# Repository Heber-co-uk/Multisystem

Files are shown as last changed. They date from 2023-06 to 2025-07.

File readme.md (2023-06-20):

# Multisystem all-in-one console motherboard designed by Heber Ltd. for MiSTer and the DE10-nano FPGA platform

### [Multisystem I/O console motherboard](https://github.com/Heber-co-uk/Multisystem/tree/main/Multisystem_All_in_One_PCB)
This all in one motherboard (console) is designed by Heber Ltd. and is released as open-source hardware for the MiSTer FPGA community and project. This console style motherboard provides SCART, VGA, Analog and Digital audio outputs, 128MB of SDRAM, SNAC with automatic level-shifters. Multisystem also has a built in 7 port USB 2.0 Hub. HDMI Isolation, fan connections, power switch, Ethernet, 2nd SD CARD interface and a dedicated expansion connector for various cartridges.

### [Multisystem 3D printed enclosure](https://www.printables.com/model/505755-mister-multisystem-v6x-2023-classic-gaming-console)
An open source enclosure is also available – designed for 3D printing (CC-BY-SA-4.0) commercial use license, over on Printables. Various other enclosures, modules, cartridges and expansion’s are also being made available all the time. Please check back for future updates and new 3D prints. 3D enclosure designed by Richard Horne @RichRap3D for Heber and the Multisystem / MiSTer project.

### Various images of the Multisystem PCB can be found [here](https://github.com/Heber-co-uk/Multisystem/tree/main/images)

### A comprehensive user manual for the Multisystem can be found [here](https://github.com/Heber-co-uk/Multisystem/tree/main/Manual)
Please check the manual if you have any questions about assembly and use of the Multisystem or the MiSTer FPGA project.

### [The official RTC daughter board is also supported on the Multisystem](https://github.com/MiSTer-devel/Hardware_MiSTer/tree/master/Addons/RTC)
This board provides real time clock. It's plugged into LTC connector.

### [Please support the MiSTer project and its creators & developers](https://patreon.com/FPGAMiSTer)
Please consider supporting the original creators for MiSTer and any of the FPGA Core developers over on Patreon or anywhere you can support or help them.

### [Alexey Melnikov](https://github.com/sorgelig)
The MiSTer project, electronics hardware, the Linux software and many FPGA cores would not have been possible without the dedicated efforts of the community, past projects like MiST and especially Alexey Melnikov for the porting over to the DE10-nano as MiSTer. Please support the project wherever you can.

### [MiSTer Forum](https://misterfpga.org/)
The MiSTer project forum can be found here.

### [RMC Retro - TheCave]( https://www.rmcretro.com/)
We would like to thank Neil at RMCRetro for the ongoing support of this project and many others for the Retro Gaming, classic computer and Arcade gaming communities. 

### [Heber Ltd.](https://heber.co.uk/) Heber are developing hardware for the Retro Gaming, classic computer and Arcade gaming communities. If you would like to know more, please visit our website or follow us on social media. 

## Notes
The PCB design and schematic is made in Altium, you will need to use Altium Designer v19.0 (or later) in order to view the source files. For convenience, [gerber files (*.zip)](https://github.com/Heber-co-uk/Multisystem/tree/main/Multisystem_All_in_One_PCB) are also included
and ready to submit to a PCB manufacturer of your choice.

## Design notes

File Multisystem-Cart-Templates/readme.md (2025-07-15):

# Heber Expansion Cartridge templates

KiCad templates for cartridges for the Multisystem and Multisystem2 / Future Multisystems.

Schematic includes the edge connector with appropriately labelled nets.

PCB includes the edge connector and a board outline.

The Multisystem cartridge also includes a micro USB 3.0 connector, which enables SNAC cartridges to be connected to other MiSTer FPGA systems. On the Multisystem, the V_SNAC signal from the edge connector and power from the USB connector will be at 5V or 3.3V depending on the voltage setting on the Multisystem, but on other MiSTer systems, the voltage from the USB connector is always 5V even when a level shifter is used. VBUS on the edge connector is current-limited 5V from the USB current limiting IC whereas 5V on the edge connector is from the main power input protected only by the main polyfuse. Also note that the SSRX and SSTX pairs are swapped in the micro USB connector; this is because the SSRX pins at the USB end connect to SSTX at the micro USB end of the cable and vice versa.

On Multisystem 2, V_SNAC is fixed at 3.3V and the level of the signals from the system are 3.3V. We recommend designing any SNAC cartridge for 5V devices with on-board level shifters so that they will be compatible with Multisystem and Multisystem 2. The common BSS138 level shifting circuit is sufficient and the pull-ups on the system side should be connected to V_SNAC for correct signal levels on the system side regardless of the position of the 5V/3.3V switch on Multisystem.

If you wish to make your own Cartridges for the Multisystem/Multisystem2, please use this template so they will be compatible.

## Board finish
Never use HASL. Use ENIG.

All official Heber cartridges feature hard gold plating on the edge contacts to improve the long term reliability of the contacts. This is an extra cost option available from most PCB manufacturers and is quite expensive to add if you are ordering prototypes; the boards will of course work without hard gold plating, but standard gold plating will wear off the pads quickly and reduce the reliability over the long term.

## Signals 
 - USB 2.0
 - GPIO Pins (3.3v)
 - Analogue input signals
 - +5V (2A max)
 - +3.3v (1A max)
 - GND
 - VBUS (Selectable voltage on the Multisystem board 3.3v or 5v)
 - Full SNAC/USER PORT
 - Digital Audio output
 - Analogue Audio output
 - RGBHV Analogue video output - various display modes & Standards.
 - Sync On Green signal

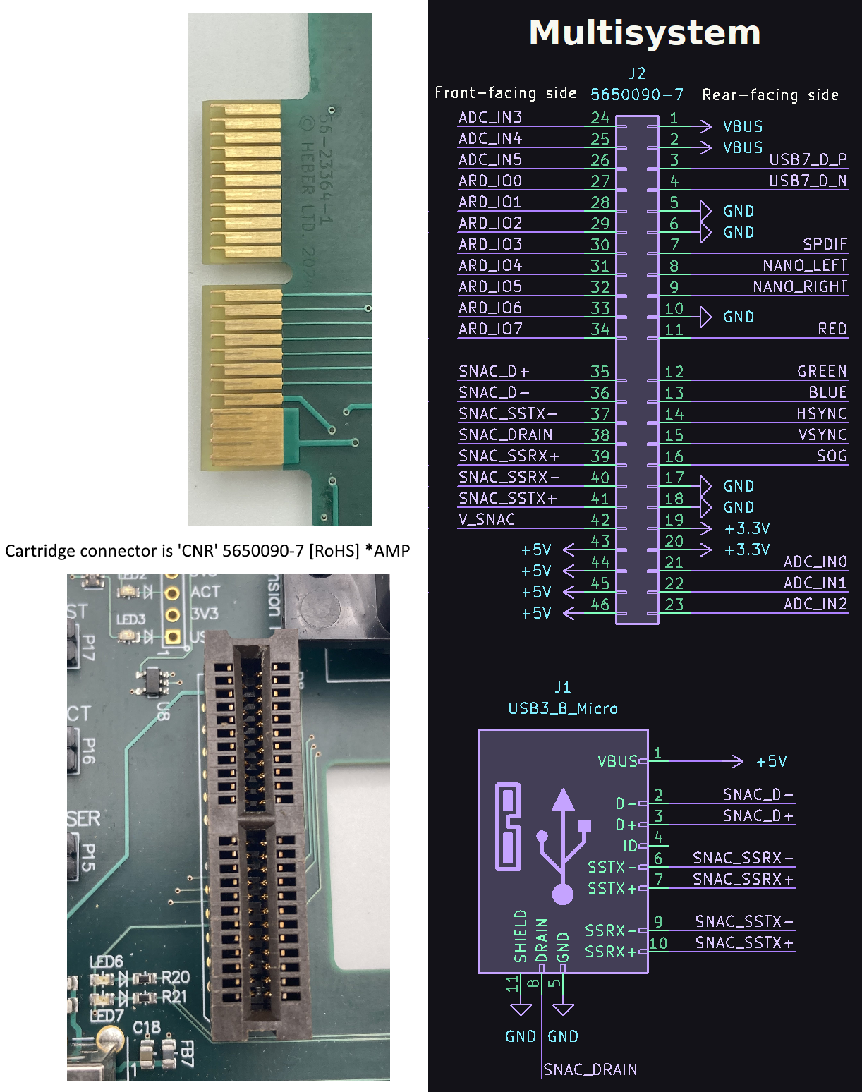
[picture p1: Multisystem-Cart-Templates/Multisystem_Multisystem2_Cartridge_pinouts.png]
Pinout of the edge connectors


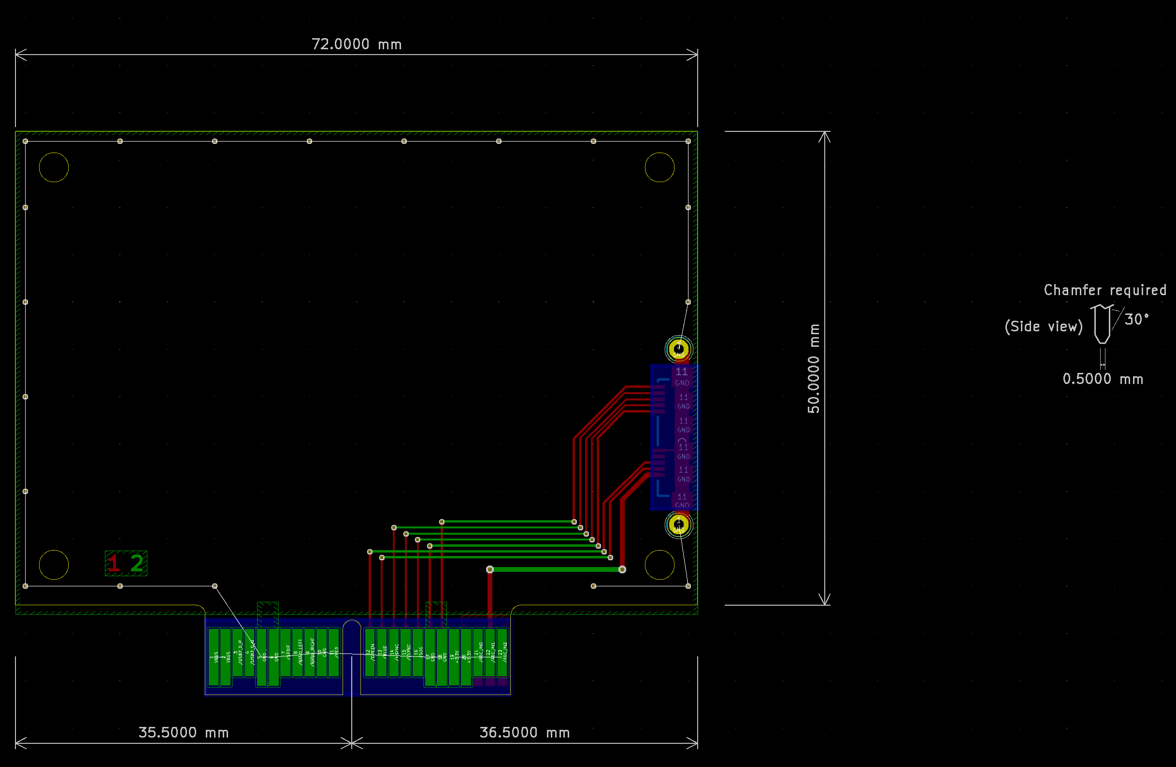
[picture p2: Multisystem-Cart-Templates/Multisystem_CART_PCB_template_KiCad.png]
Multisystem1/2 Cartridge PCB KiCad template


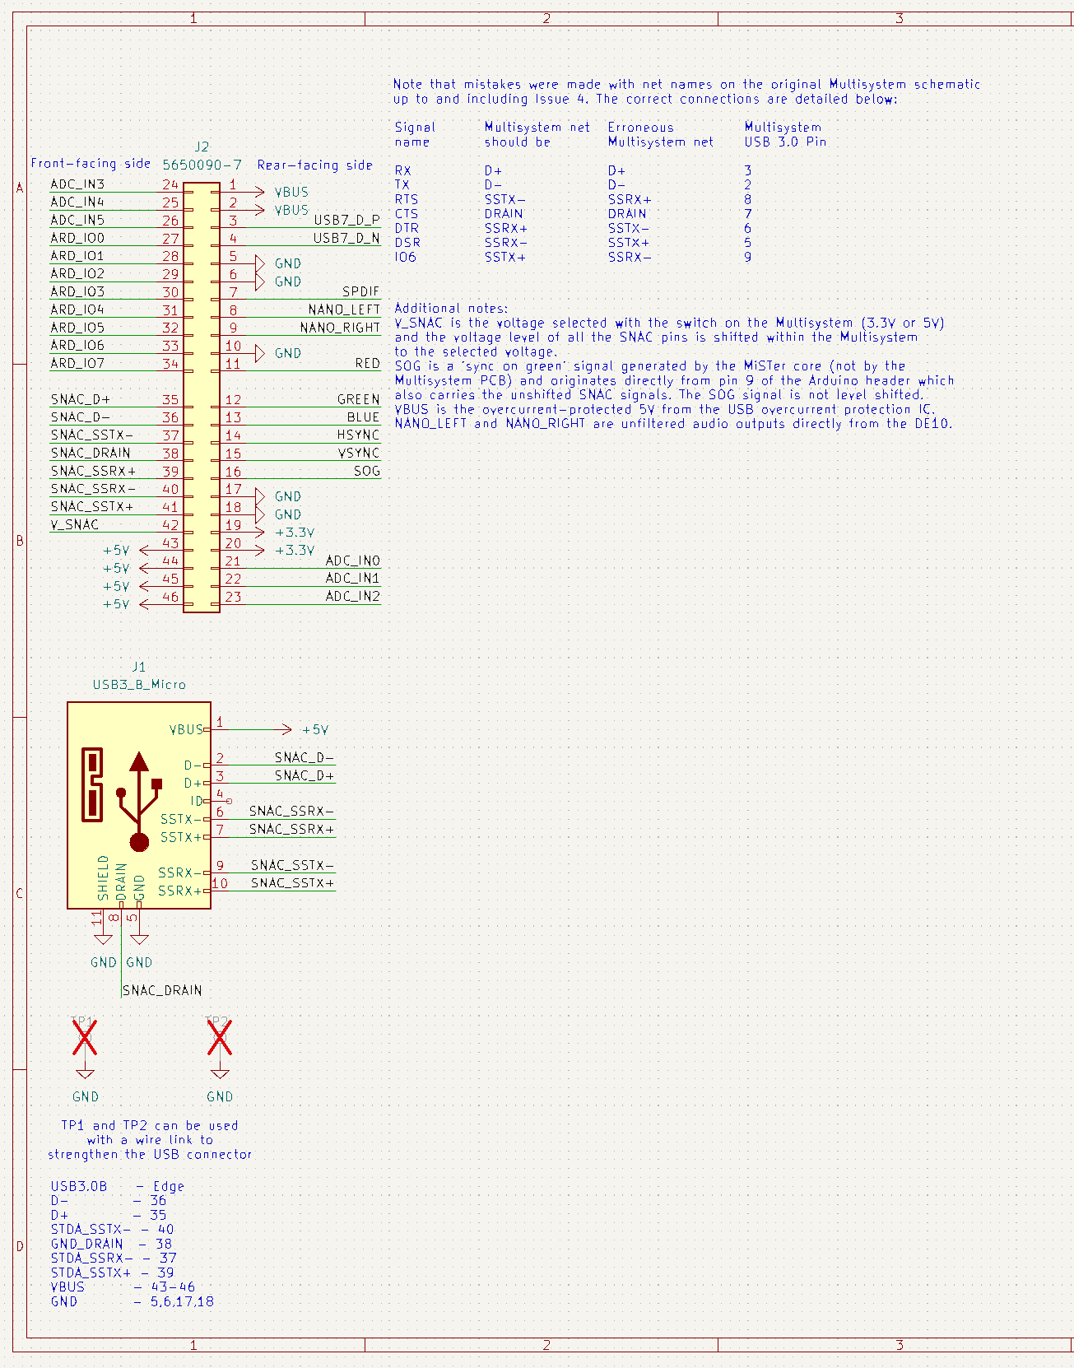
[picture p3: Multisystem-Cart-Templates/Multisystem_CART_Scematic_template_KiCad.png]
Multisystem1/2 Cartridge Schematic KiCad template


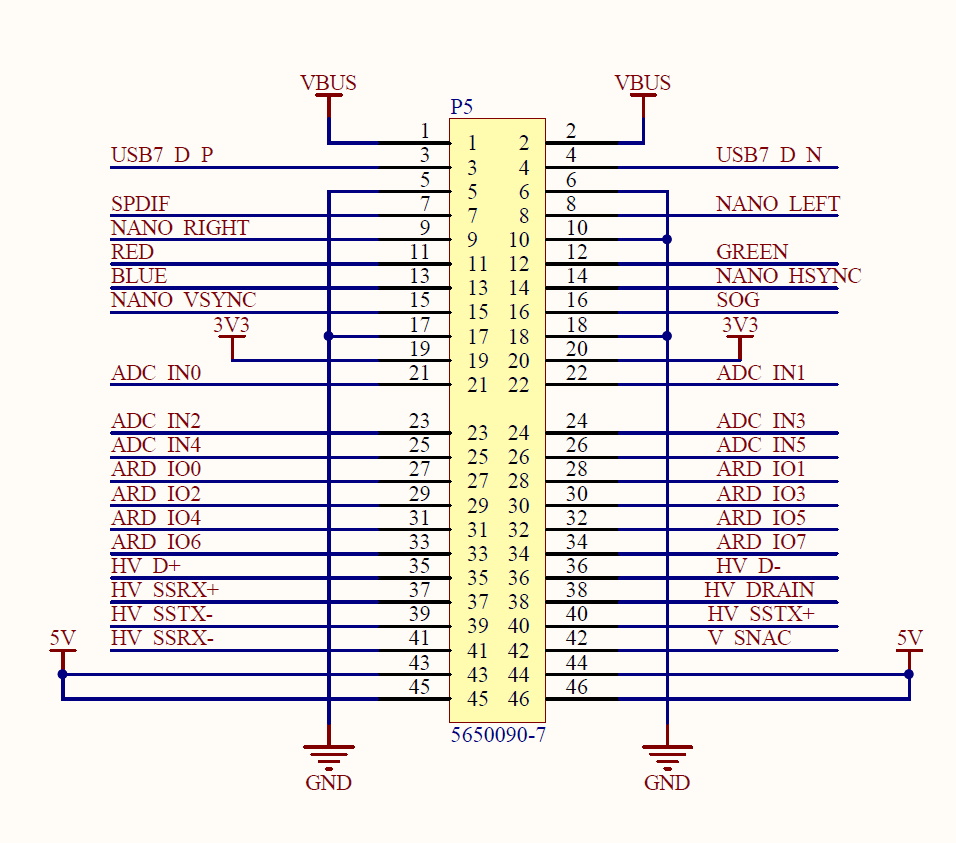
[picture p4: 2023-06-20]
images/Expansion_connections_schematic.jpg

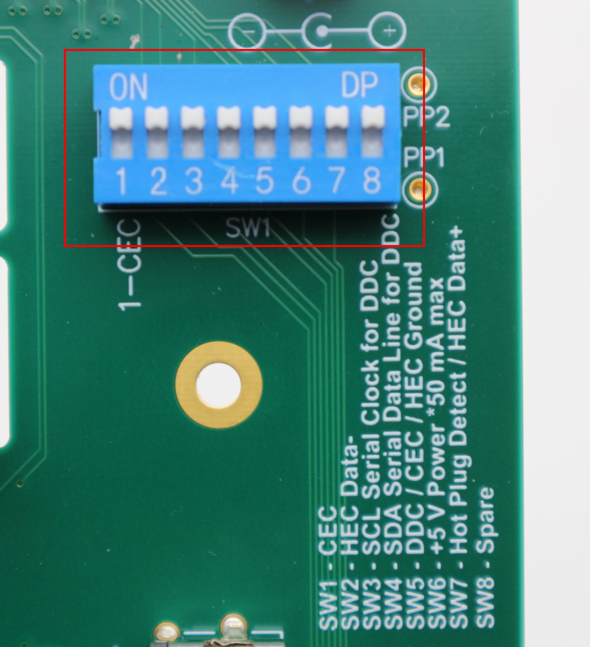
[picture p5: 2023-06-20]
images/Multisystem_HDMI_Isolation_SWITCHES.jpg

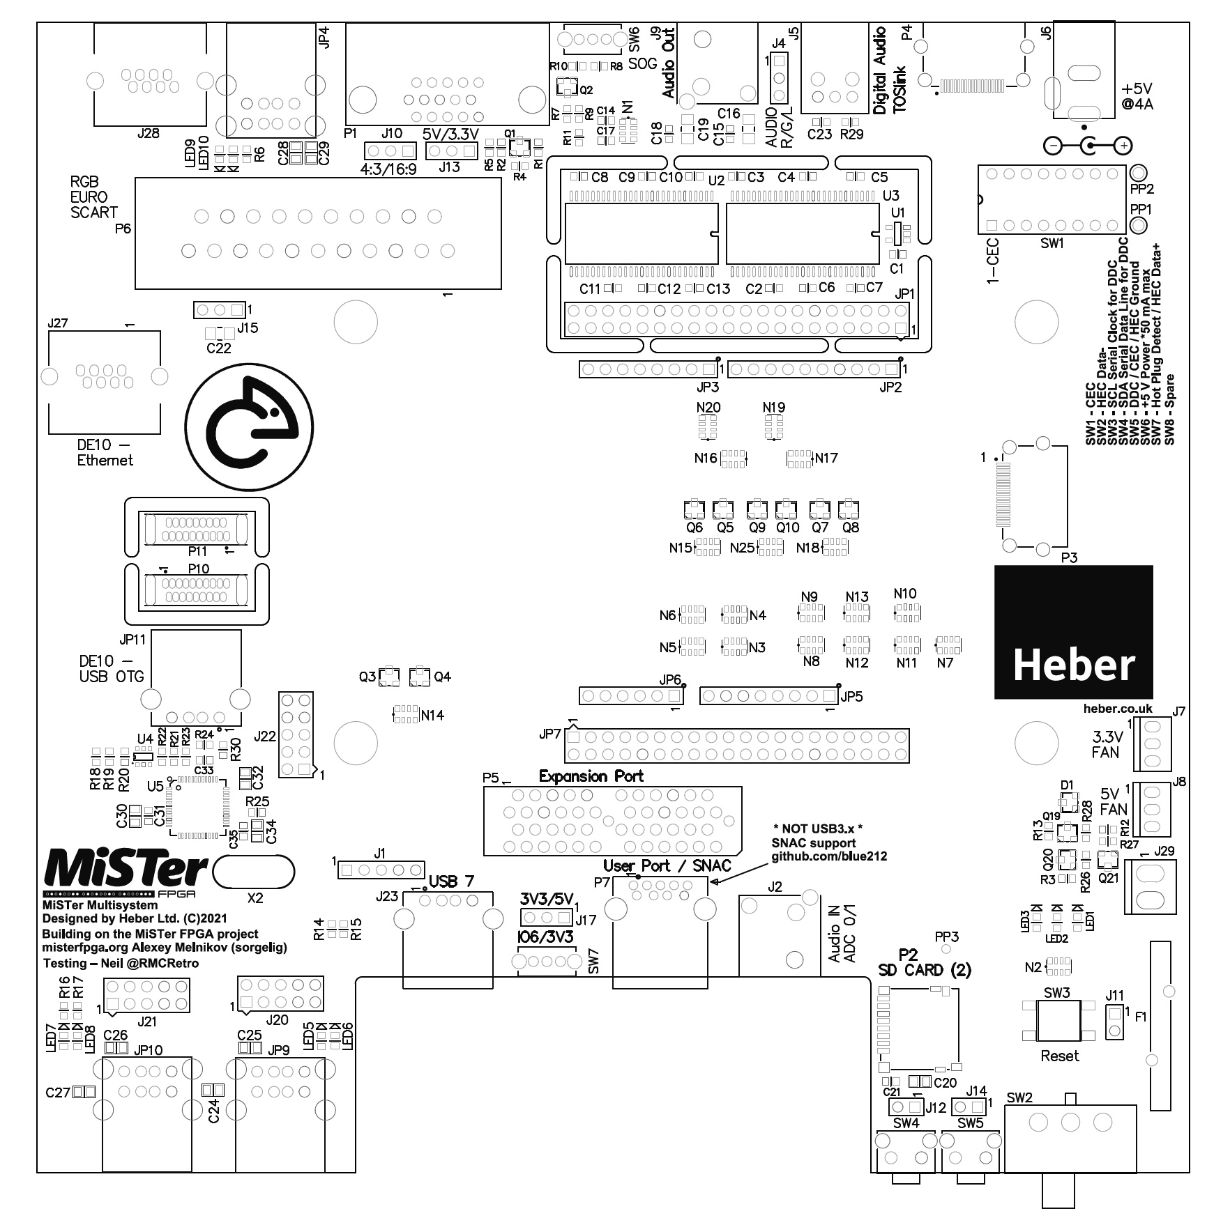
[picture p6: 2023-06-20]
images/Multisystem_board_outline.jpg

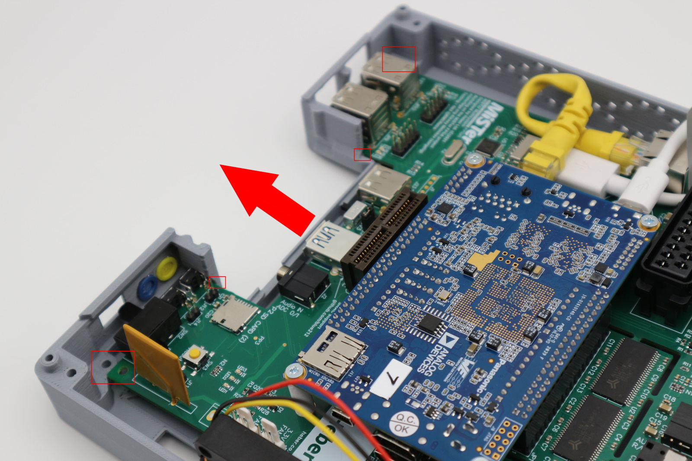
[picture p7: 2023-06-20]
images/Multisystem_Case_fitting_board_and_user_buttons.jpg

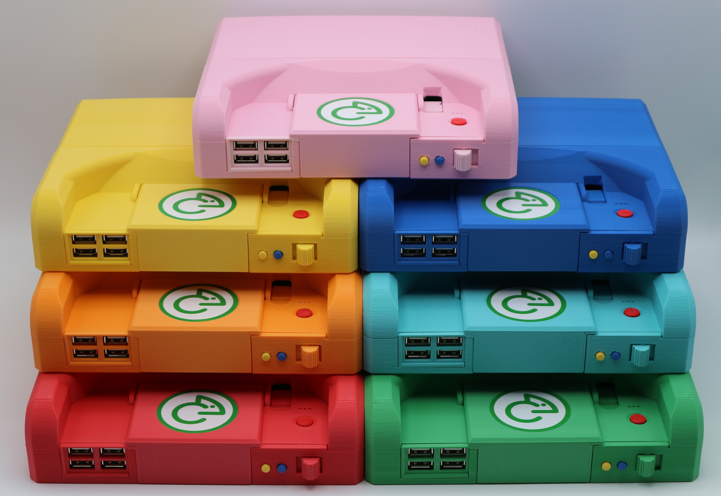
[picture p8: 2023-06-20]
images/Multisystem_V5_Rainbow_FULL_SIZE.jpg

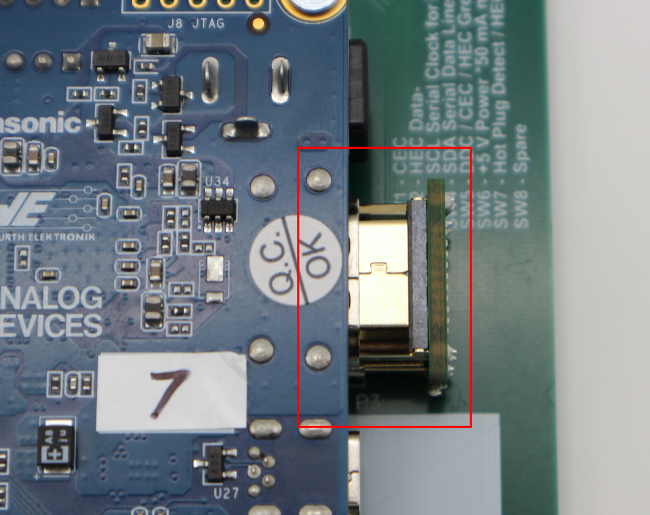
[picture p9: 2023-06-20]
images/Multisystem_HDMI_BRIDGE_BOARD_correctly_fitted.jpg

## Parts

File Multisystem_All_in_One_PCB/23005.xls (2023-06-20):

Comment | Description | Designator | Footprint | LibRef | Quantity
100nF |  | C1, C21, C23, C31, C33, C35 | SM0603 | C | 6
1uF |  | C2, C3, C4, C5, C6, C7, C8, C9, C10, C11, C12, C13 | SM0603 | C | 12
10nF SM0603 |  | C14, C15, C17, C18 | SM0603 | C | 4
100uF 10V |  | C16, C19, C22 | SM1206 | CAP_POL | 3
10uF |  | C20, C24, C25, C26, C27, C28, C29, C30, C32, C34 | SM0805 | C | 10
BZX84C5V1 |  | D1 | SOT23 | ZENNER_SOT23 | 1
MF-RX375/72-2 |  | F1 | FUSE-MF-RX375/72-2 | FUSE | 1
5W SIL |  | J1 | 5WSIL | HEADER 5W SIL | 1
PHONEJACK STEREO_RA |  | J2, J9 | JACKSOCKET-STEREO | PHONEJACK STEREO_RA | 2
3W SIL |  | J4, J10, J13, J15, J17 | 3WSIL | HEADER 3 | 5
FC684208T |  | J5 | FCR684208T | HEADER 3 | 1
PJ-202A 3.5MM Power Jack |  | J6 | CUI_PJ-202A | PLUG 3W SIL | 1
HEADER 3 |  | J7, J8 | 3W0.1KK | HEADER 3 | 2
2W SIL |  | J11, J12, J14 | 2WSIL | HEADER 2 | 3
HEADER 5X2 |  | J20, J21, J22 | 10WHDR_5X2 | HEADER 5X2 | 3
USB-A |  | J23, JP11 | USB_WURTH_61400416021 | USB-A | 2
RJ-45 |  | J27, J28 | P-RJHSE-XE80 | RJ45 | 2
0.156K 2W |  | J29 | 2W156KK | HEADER 2 | 1
HEADER 20X2 |  | JP1, JP7 | 40WHDR_20X2 - DE10-NANO | HEADER 20X2 | 2
HEADER 10 |  | JP2 | 10WSIL | HEADER 10 | 1
HEADER 8 |  | JP3, JP5 | 8WSIL | HEADER 8 | 2
DUAL USB-A |  | JP4, JP9, JP10 | USB_STACK | USB-A_DUAL | 3
HEADER 6W |  | JP6 | 6WSIL | HEADER 6W | 1
LED |  | LED1, LED2, LED3 | SM0603LED_1 | LED | 3
GREEN |  | LED5, LED6, LED7, LED8, LED9, LED10 | SM0603LED_1 | LED | 6
560R SM1206 |  | N1 | 1206RES4_I2 | RESISTOR DIP 4 | 1
56R SM1206 |  | N2 | 1206RES4_I2 | RESISTOR DIP 4 | 1
470R SM1206 |  | N3, N5, N7, N8, N11, N12 | 1206RES4_I2 | RESISTOR DIP 4 | 6
240R SM1206 |  | N4, N6, N9, N10, N13 | 1206RES4_I2 | RESISTOR DIP 4 | 5
10K |  | N14, N15, N18, N19, N20, N25 | 1206RES4_I2 | RESISTOR DIP 4 A-D, RESISTOR DIP 4 | 6
100R |  | N16, N17 | 1206RES4_I2 | RESISTOR DIP 4 | 2
DB15 VGA |  | P1 | 15WVGASKTRA | CONNECTOR DB15 VGA SHIELDED | 1
uSDCARD |  | P2 | AMP_114-00841-68 | uSDCARD | 1
HDMI_CON |  | P3, P4 | AMPFCI_1029449 | HDMI_CON | 2
5650090-7 |  | P5 | AMC_RISER2 | 5650090-7 | 1
SCART |  | P6 | K-SCART-024 | SCART | 1
CONN USB 9 WAY |  | P7 | WURTH_692121030100 | CONN USB 9 WAY | 1
HDMI_CON |  | P10, P11 | HDMI_VERT_PTH | HDMI_CON | 2
PROBEPOINT_SHORT |  | PP1, PP2 | 1MM_WIRING | PROBEPOINT_SHORT | 2
PROBEPOINT_SHORT |  | PP3, PP4, PP5, PP6, PP7, PP8, PP9, PP10, PP11, PP12, PP13, PP14, PP15 | PROBEPOINT | PROBEPOINT_SHORT | 13
BC848 |  | Q1 | SOT23 | BC846AL_1 | 1
BC847 |  | Q2 | SOT23 | BC846AL_1 | 1
BSS138 |  | Q3, Q4, Q5, Q6, Q7, Q8, Q9, Q10 | SOT23 | MOSFET N_0 | 8
MMSS8550H |  | Q19 | SOT23 | BC856AL | 1
DMP2066LSN-7 |  | Q20, Q21 | SOT23 | MOSFET P | 2
820R SM0603 |  | R1 | SM0603 | RES | 1
1K2 SM0603 |  | R2 | SM0603 | RES | 1
6K8 |  | R3, R13 | SM0603 | RES | 2
68R SM0603 |  | R4, R6 | SM0603 | RES | 2
3K3 SM0603 |  | R5 | SM0603 | RES | 1
100R SM0603 |  | R7, R11 | SM0603 | RES | 2
DNF |  | R8 | SM0603 | RES | 1
1K SM0603 |  | R9, R10, R29 | SM0603 | RES | 3
30K |  | R12, R27 | SM0603 | RES | 2
510R |  | R14, R15, R16, R17, R18, R19 | SM0603 | RES | 6
5K6 SM0603 |  | R20 | SM0603 | RES | 1
0R |  | R21 | SM0603 | RES | 1
10K SM0603 |  | R22 | SM0603 | RES | 1
10K |  | R23 | SM0603 | RES | 1
47K |  | R24 | SM0603 | RES | 1
2K7 |  | R25 | SM0603 | RES | 1
100K |  | R26, R30 | SM0603 | RES | 2
330R |  | R28 | SM0603 | RES | 1
SW DIP-8 |  | SW1 | 8WSWITCH | SW DIP-8 | 1
SW SPDT |  | SW2 | SW_CK_L102011ml04Q | SW SPDT | 1
PUSHBUTTON |  | SW3 | SW_SM_6MM | SW PUSHBUTTON | 1
SW PUSHBUTTON VERT |  | SW4, SW5 | SW_TS6H2A | SW PUSHBUTTON VERT | 2
SW SPDT |  | SW6, SW7 | SW_ITT_OS102011MS2QN1 | SW SPDT | 2
SN74LVC1G04 |  | U1 | SOT23-5 | SN74LVC1G07 | 1
AS4C32M16SB |  | U2, U3 | TSOP54/080 | AS4C32M16SB | 2
NCP380LSNAJAAT1G |  | U4 | SOT23-6LEAD | NCP380LSNAJAAT1G | 1
FE2.1 |  | U5 | LQFP48 | FE2.1 | 1
12MHz |  | X2 | HC49_I3 | XTAL | 1

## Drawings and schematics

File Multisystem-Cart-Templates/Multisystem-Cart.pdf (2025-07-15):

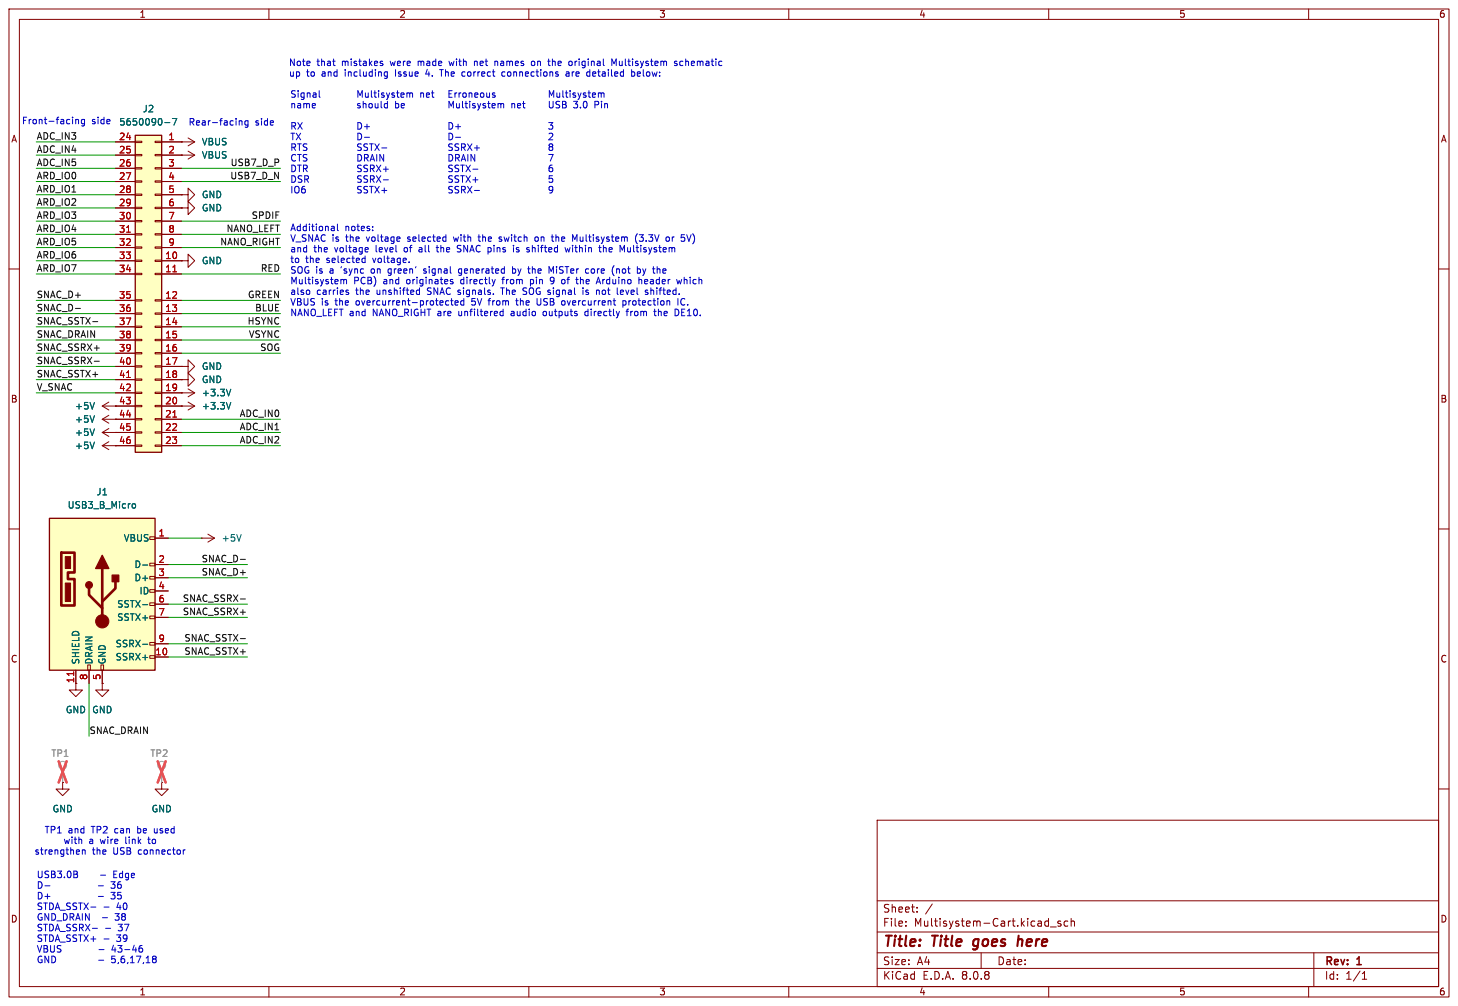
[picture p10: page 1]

File: Multisystem-Cart.kicad_sch Sheet: /
Id: 1/1 Title: Title goes here

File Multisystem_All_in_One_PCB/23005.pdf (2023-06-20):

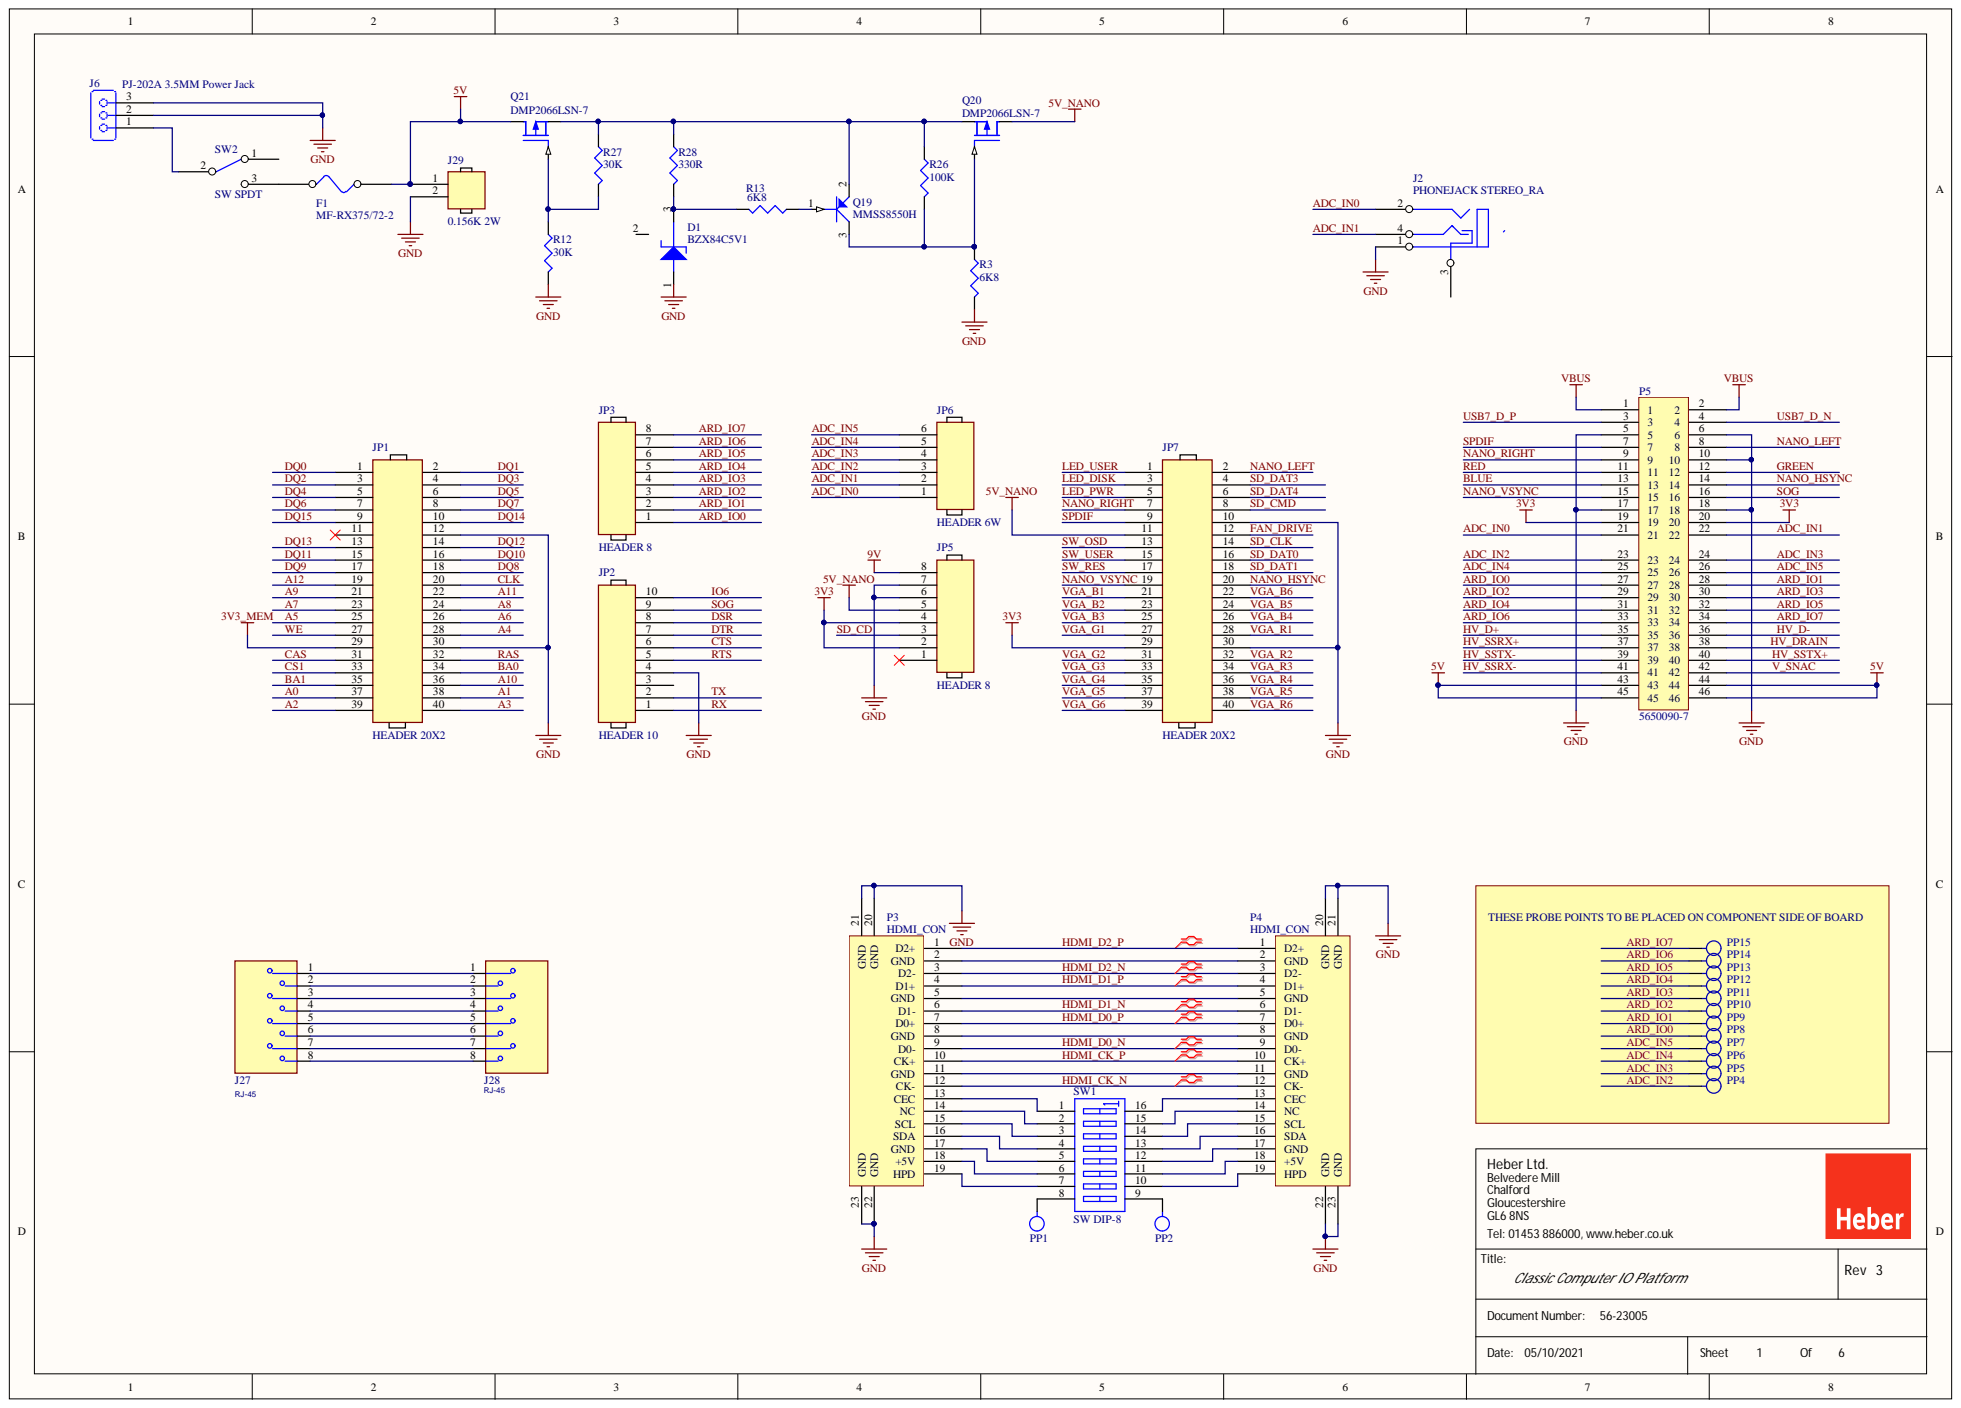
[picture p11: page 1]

THESE PROBE POINTS TO BE PLACED ON COMPONENT SIDE OF BOARD

6 | 11
7 | 10

Heber Ltd. Belvedere Mill

Tel: 01453 886000, www.heber.co.uk

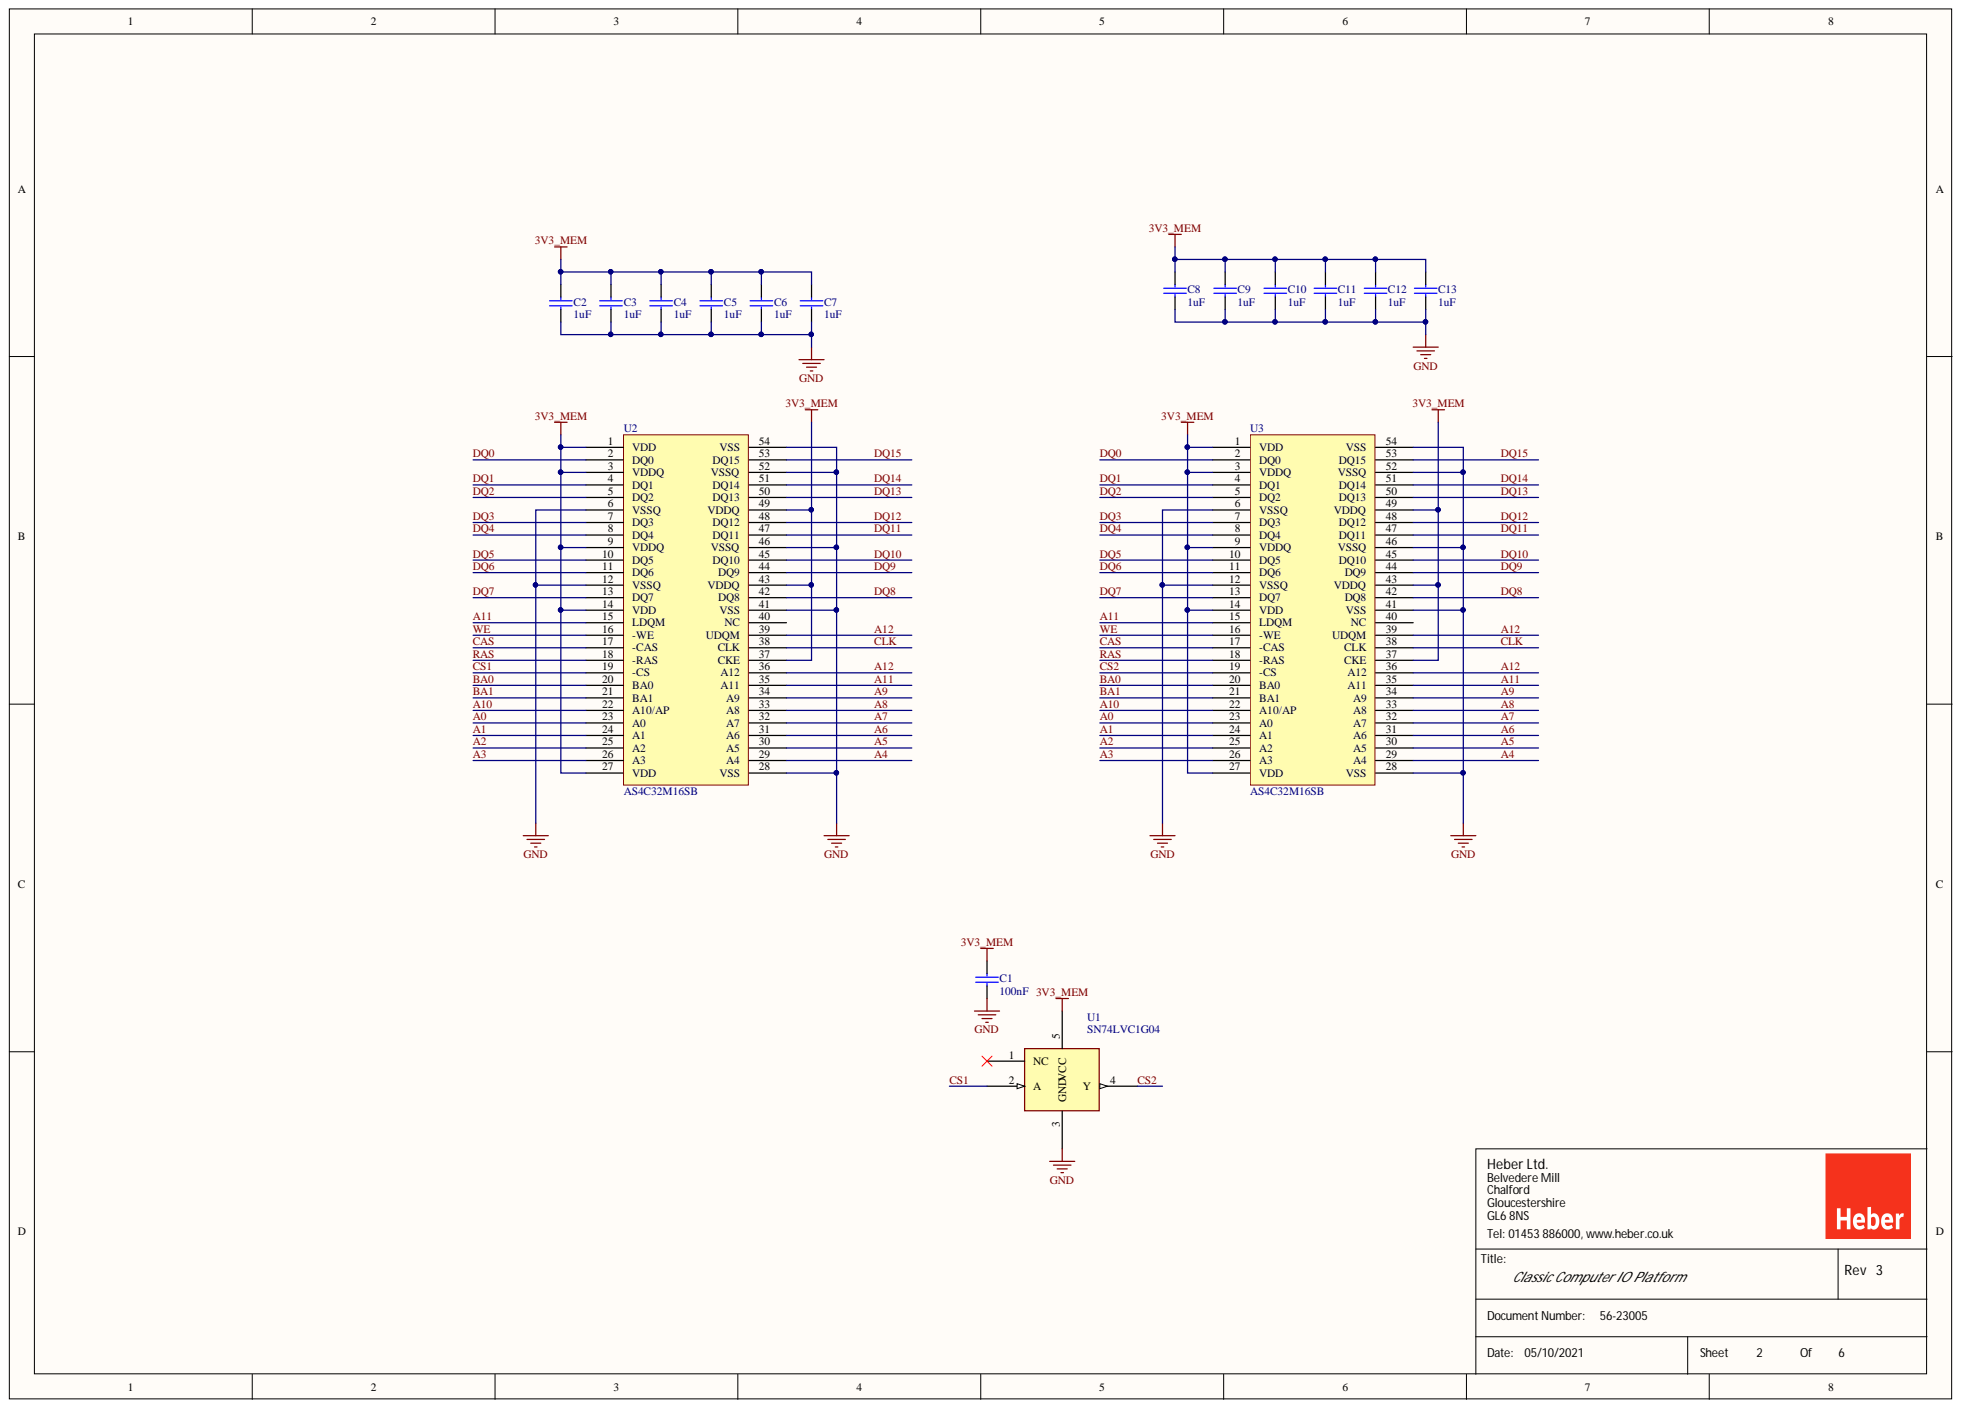
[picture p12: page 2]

Heber Ltd. Belvedere Mill

Tel: 01453 886000, www.heber.co.uk

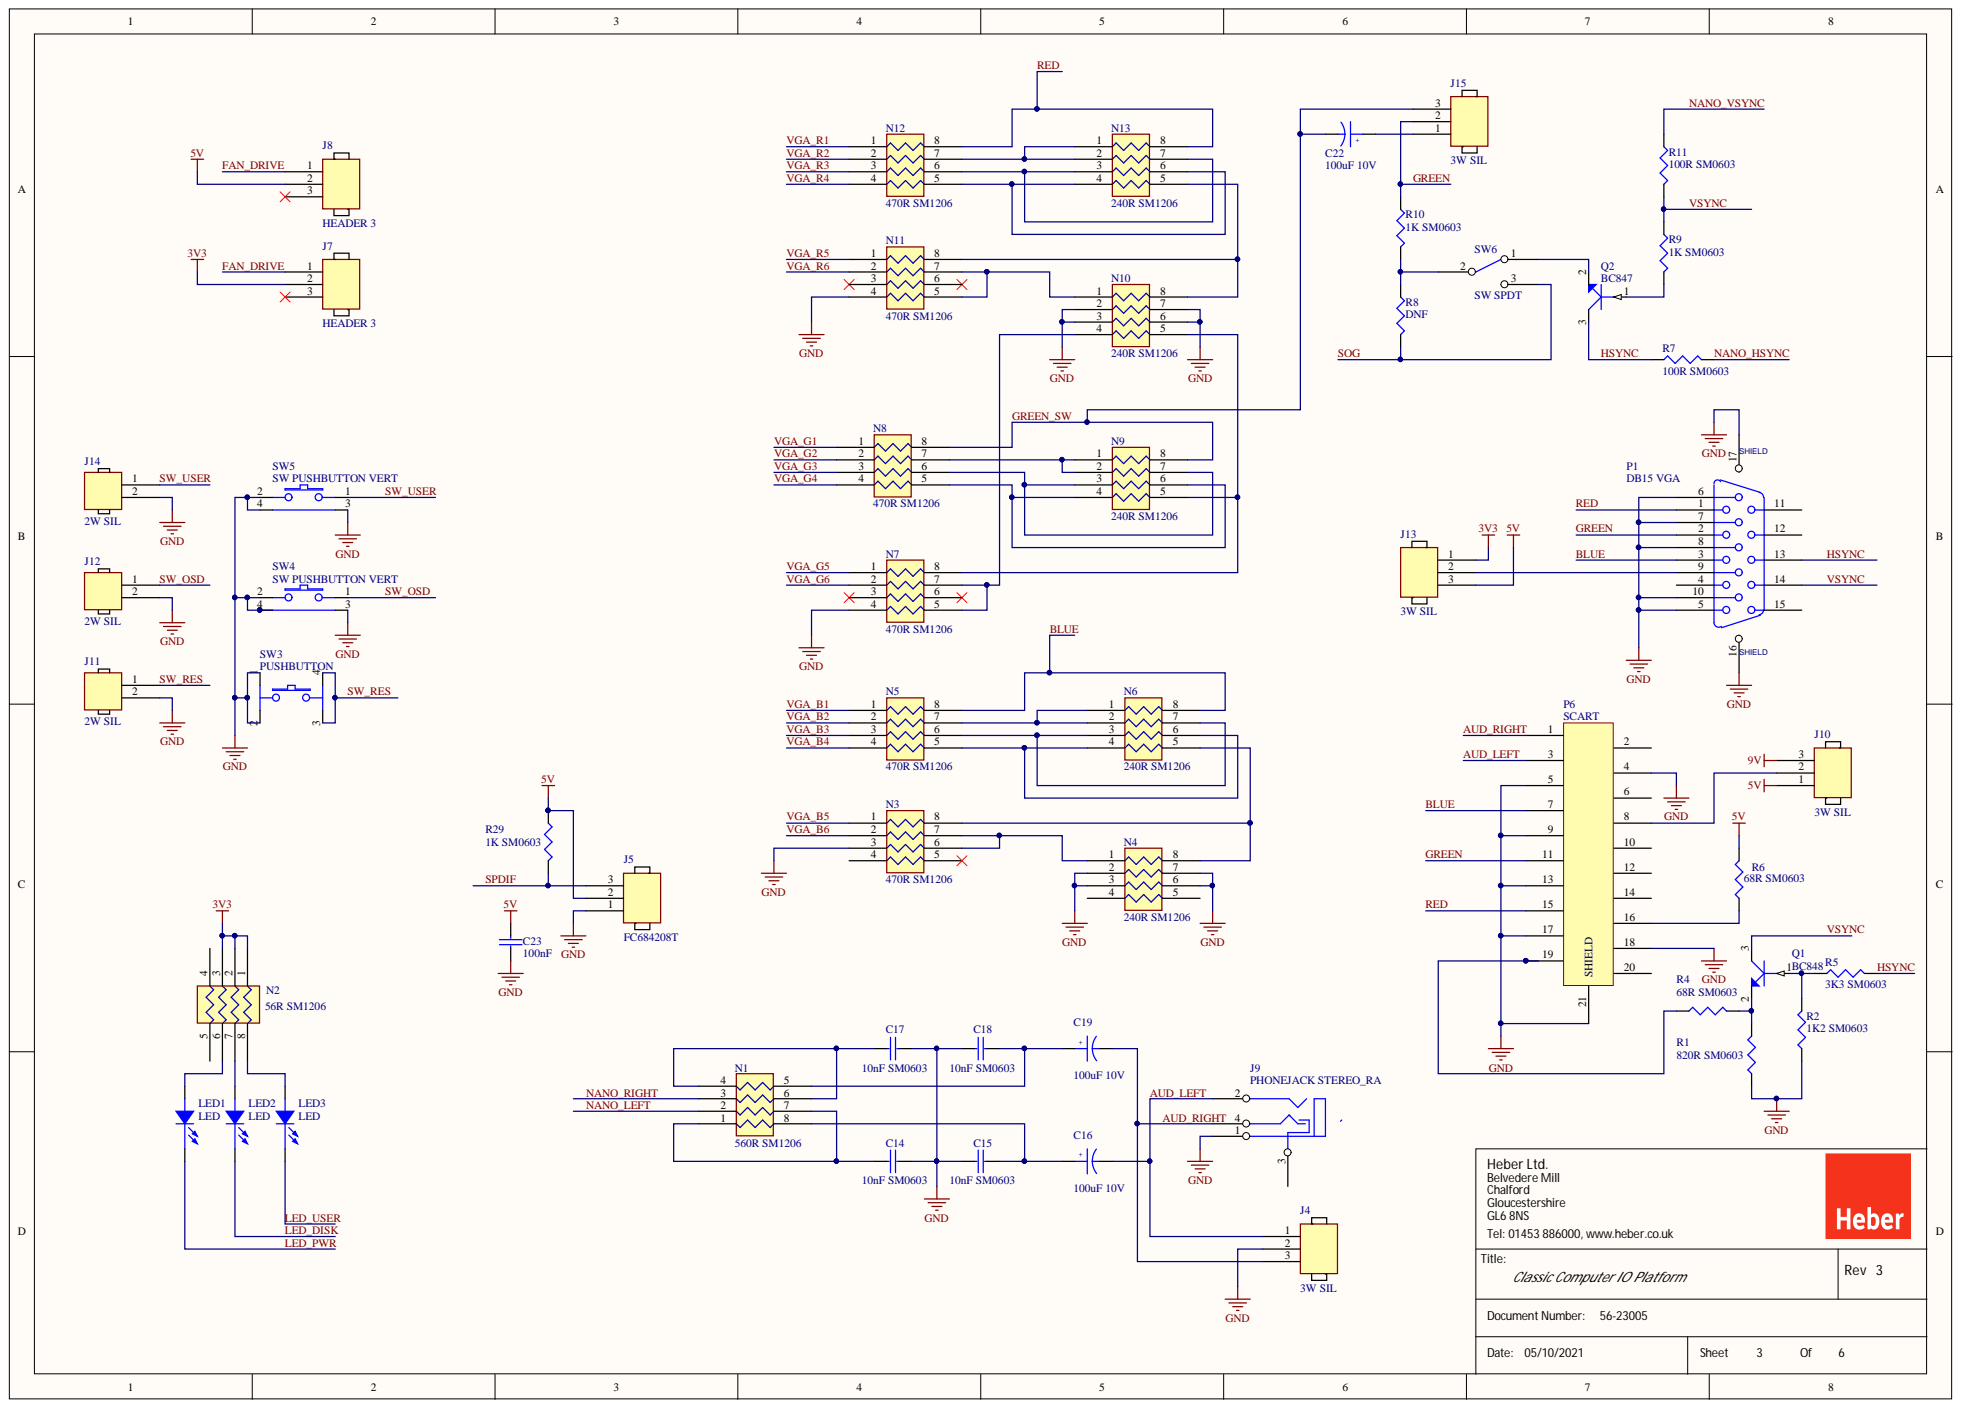
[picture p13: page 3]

GREEN_SW

Heber Ltd. Belvedere Mill

LED_USER

Tel: 01453 886000, www.heber.co.uk

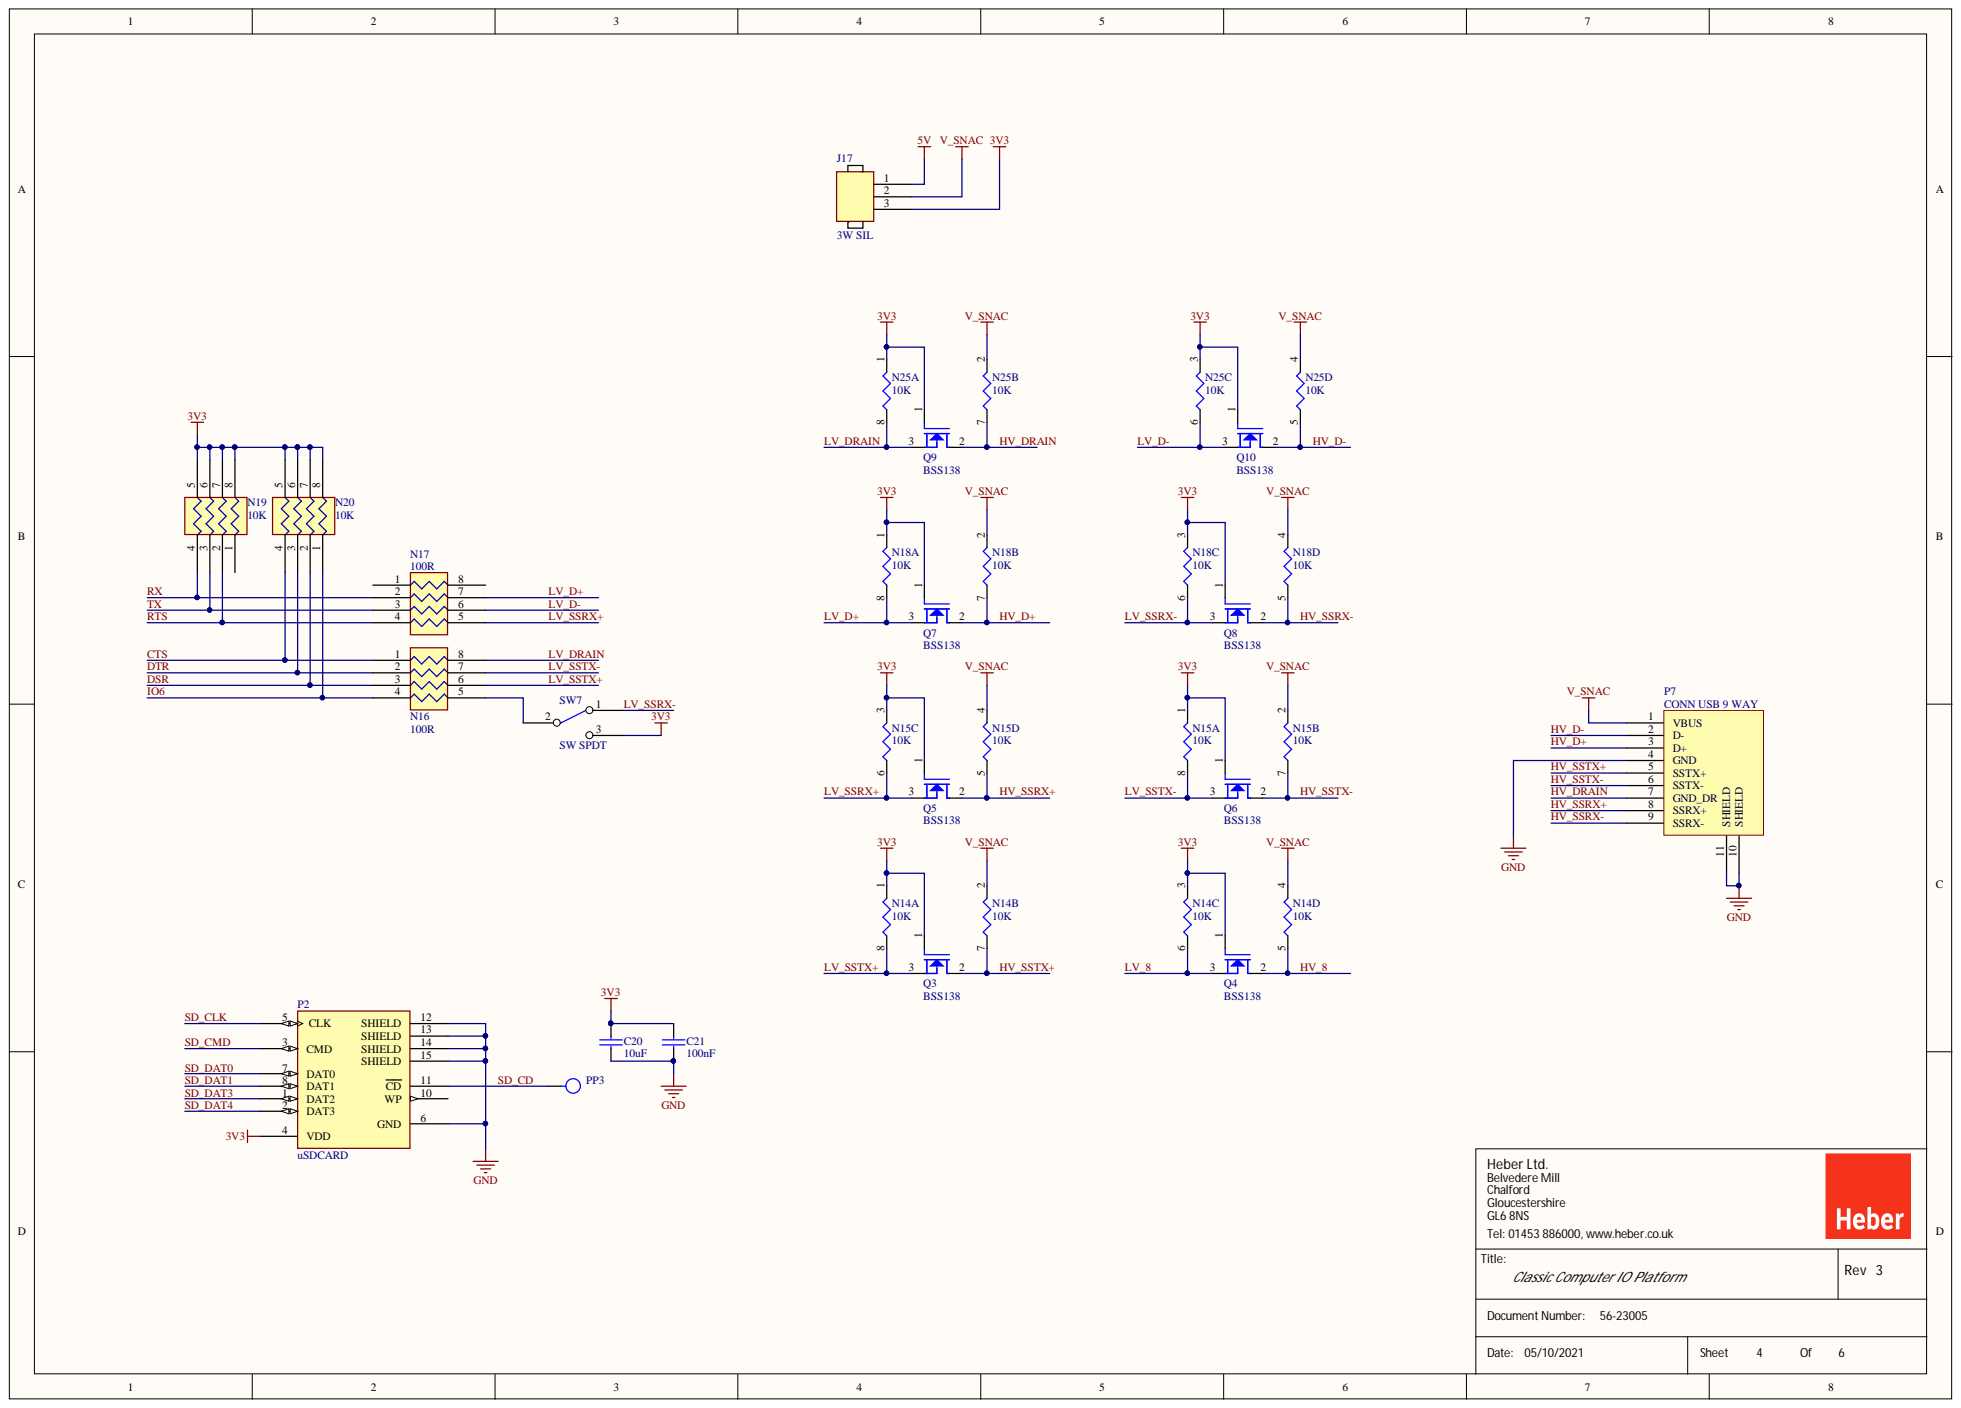
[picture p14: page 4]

RX
TX | 3
RTS

CTS
DTR | 2
DSR | 3
IO6

Heber Ltd. Belvedere Mill

Tel: 01453 886000, www.heber.co.uk

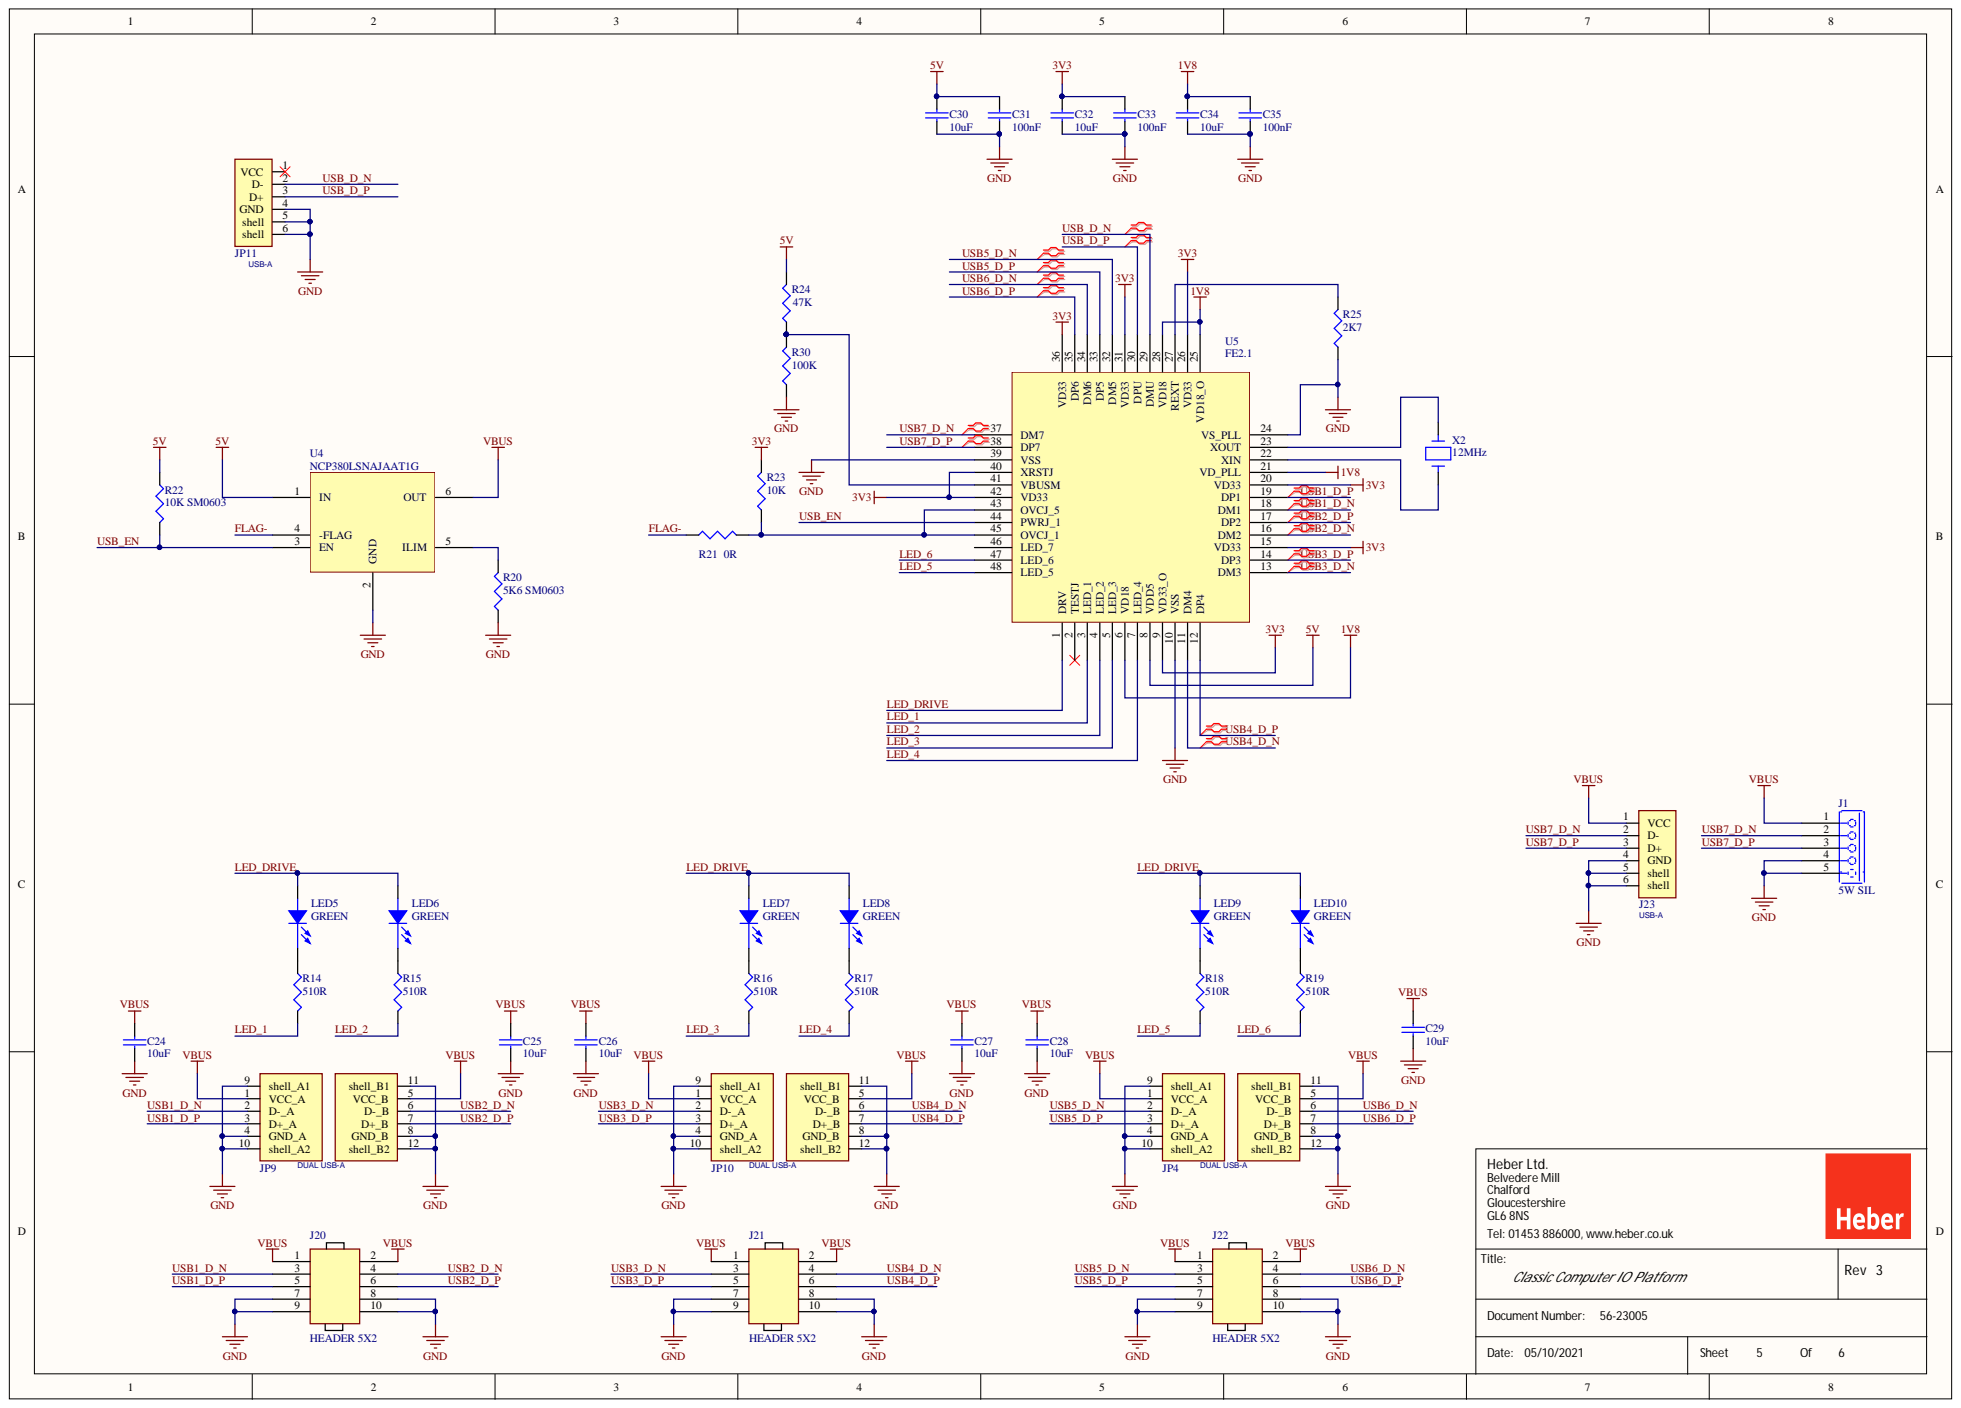
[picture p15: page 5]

USB5_D_P
USB6_D_N

Heber Ltd. Belvedere Mill

Tel: 01453 886000, www.heber.co.uk

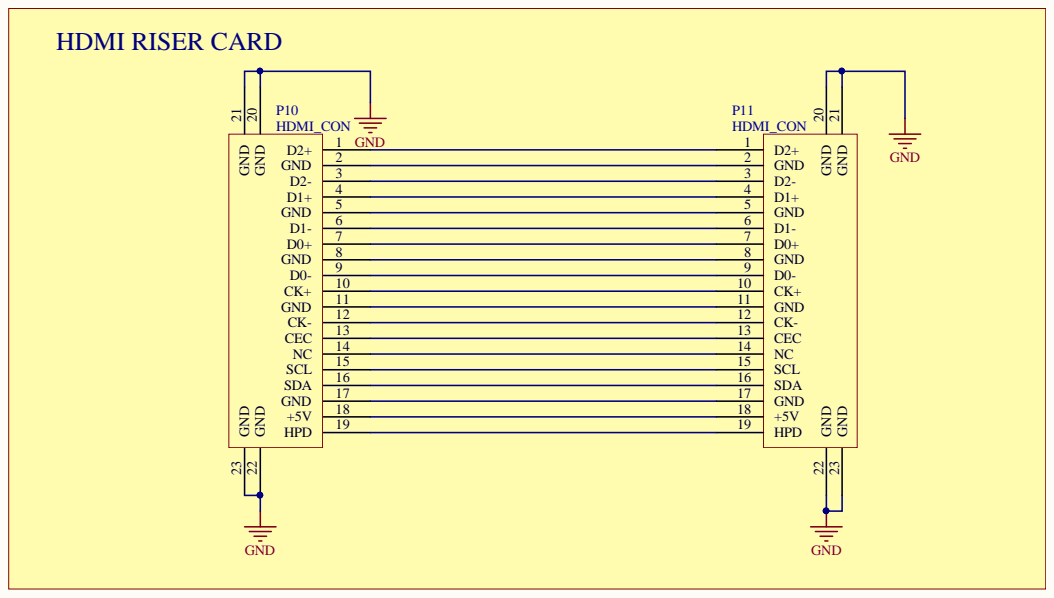
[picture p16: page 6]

GND 22 GND 23 GND 21 GND 20

td. Belvedere Mill Chalford

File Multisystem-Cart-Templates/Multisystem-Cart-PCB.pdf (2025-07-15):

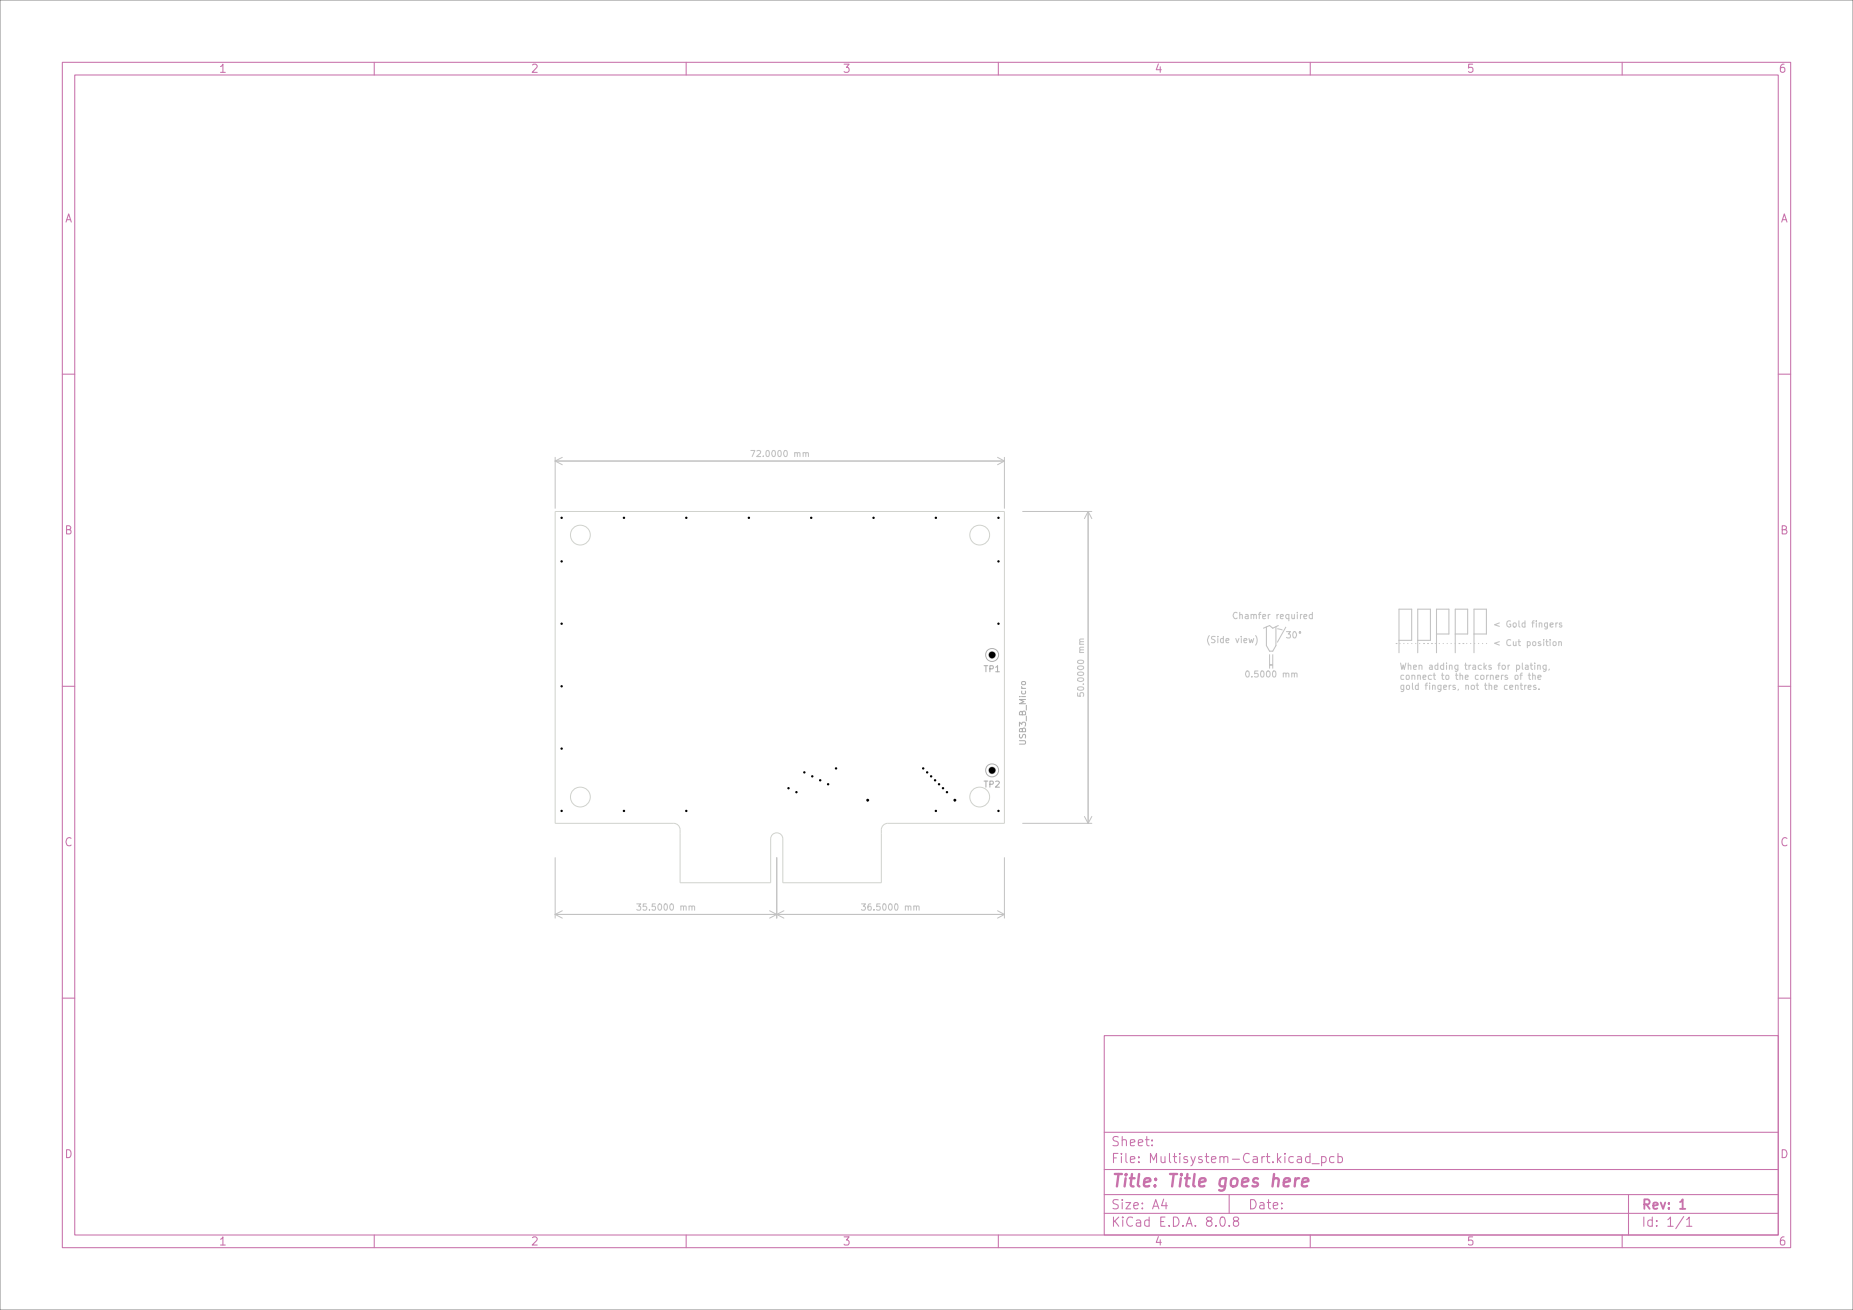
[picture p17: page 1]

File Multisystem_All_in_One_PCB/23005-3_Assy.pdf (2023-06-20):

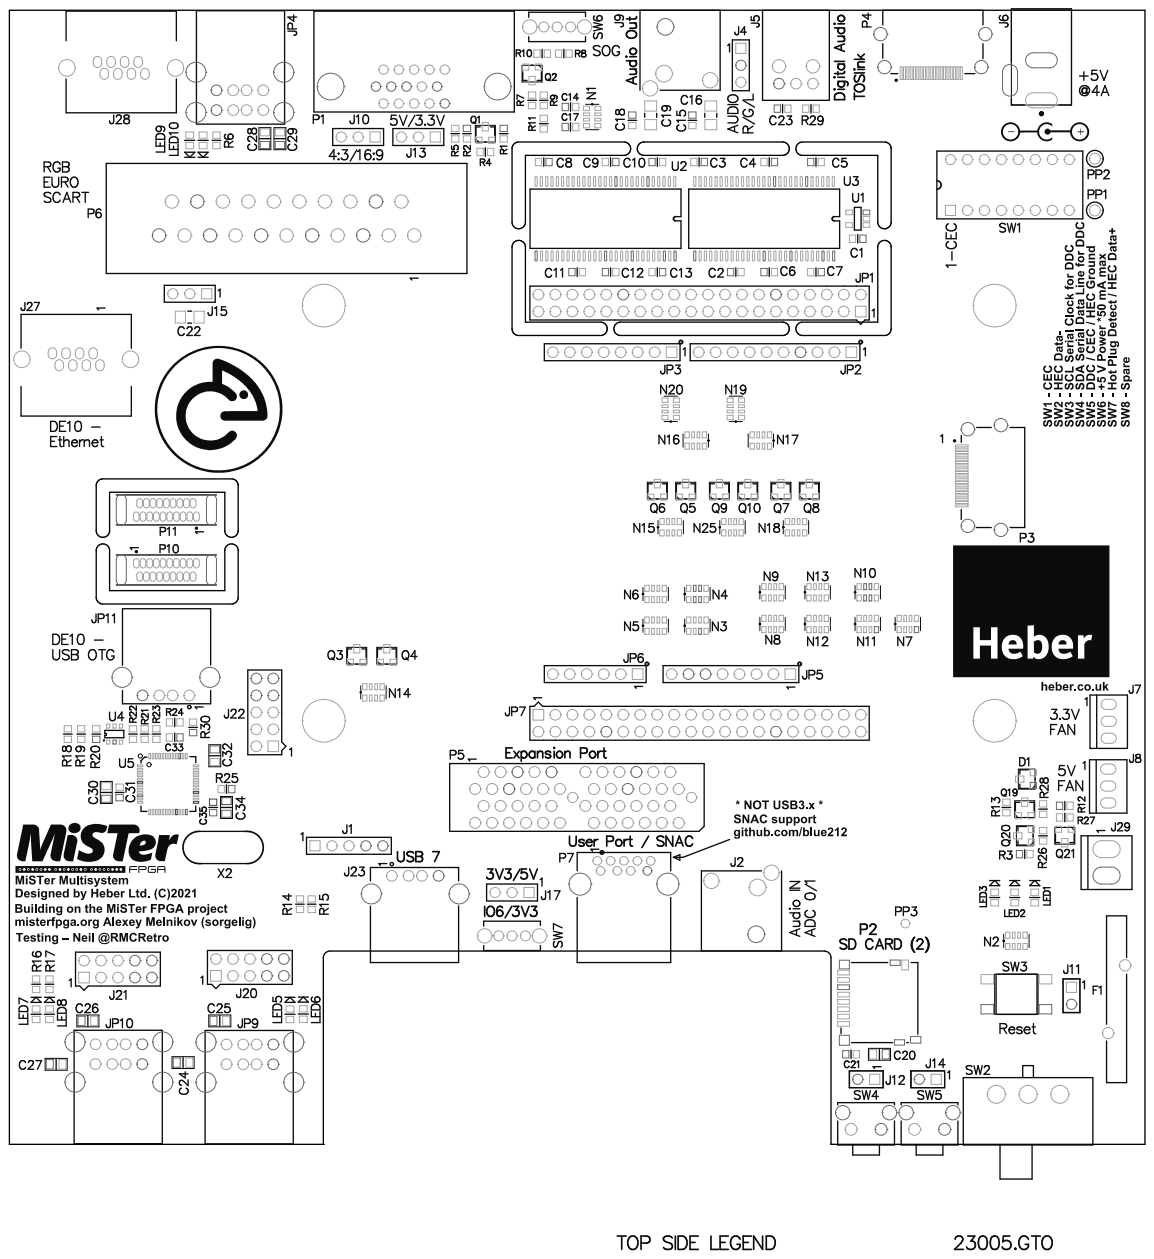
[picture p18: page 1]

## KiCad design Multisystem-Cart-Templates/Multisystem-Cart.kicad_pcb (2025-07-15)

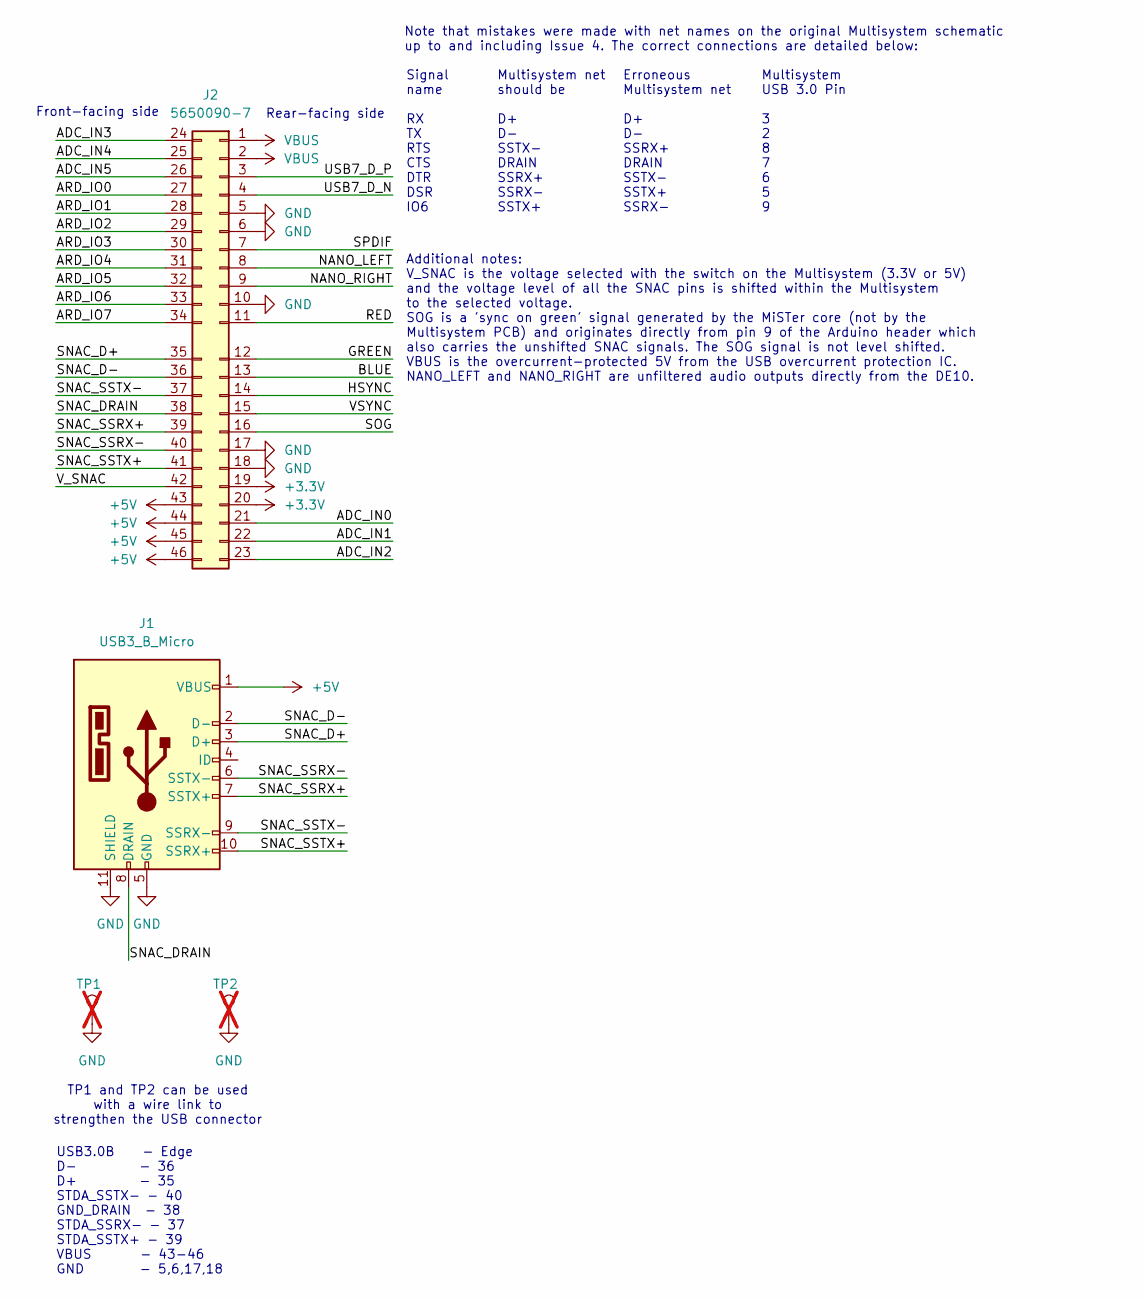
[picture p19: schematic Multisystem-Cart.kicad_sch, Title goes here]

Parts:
J1: USB3_B_Micro; CONN-MICRO-USB-3
J2: 5650090-7; PCI_EDGE_AMC_RISER_MULTISYSTEM
TP1, TP2: TestPoint; Pin_D1.0mm_L10.0mm; not fitted

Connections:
+3.3V: J2.19, J2.20
+5V: J1.1 (VBUS), J2.43, J2.44, J2.45, J2.46
/ADC_IN0: J2.21
/ADC_IN1: J2.22
/ADC_IN2: J2.23
/ADC_IN3: J2.24
/ADC_IN4: J2.25
/ADC_IN5: J2.26
/ARD_IO0: J2.27
/ARD_IO1: J2.28
/ARD_IO2: J2.29
/ARD_IO3: J2.30
/ARD_IO4: J2.31
/ARD_IO5: J2.32
/ARD_IO6: J2.33
/ARD_IO7: J2.34
/BLUE: J2.13
/GREEN: J2.12
/HSYNC: J2.14
/NANO_LEFT: J2.8
/NANO_RIGHT: J2.9
/RED: J2.11
/SNAC_D+: J1.3 (D+), J2.35
/SNAC_D-: J1.2 (D-), J2.36
/SNAC_DRAIN: J1.8 (DRAIN), J2.38
/SNAC_SSRX+: J1.7 (SSTX+), J2.39
/SNAC_SSRX-: J1.6 (SSTX-), J2.40
/SNAC_SSTX+: J1.10 (SSRX+), J2.41
/SNAC_SSTX-: J1.9 (SSRX-), J2.37
/SOG: J2.16
/SPDIF: J2.7
/USB7_D_N: J2.4
/USB7_D_P: J2.3
/VSYNC: J2.15
/V_SNAC: J2.42
GND: J1.5 (GND), J1.11 (SHIELD), J2.5, J2.6, J2.10, J2.17, J2.18, TP1.1, TP2.1
VBUS: J2.1, J2.2

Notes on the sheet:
Erroneous Multisystem net D+ D- SSRX+ DRAIN SSTX- SSTX+ SSRX-
USB3.0B - Edge D- - 36 D+ - 35 STDA_SSTX- - 40 GND_DRAIN - 38 STDA_SSRX- - 37 STDA_SSTX+ - 39 VBUS - 43-46 GND - 5,6,17,18
Signal name RX TX RTS CTS DTR DSR IO6
Front-facing side
TP1 and TP2 can be used with a wire link to strengthen the USB connector
Multisystem USB 3.0 Pin 3 2 8 7 6 5 9
Multisystem net should be D+ D- SSTX- DRAIN SSRX+ SSRX- SSTX+
Note that mistakes were made with net names on the original Multisystem schematic up to and including Issue 4. The correct connections are detailed below:
Rear-facing side
Additional notes: V_SNAC is the voltage selected with the switch on the Multisystem (3.3V or 5V) and the voltage level of all the SNAC pins is shifted within the Multisystem to the selected voltage. SOG is a 'sync on green' signal generated by the MiSTer core (not by the Multisystem PCB) and origin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

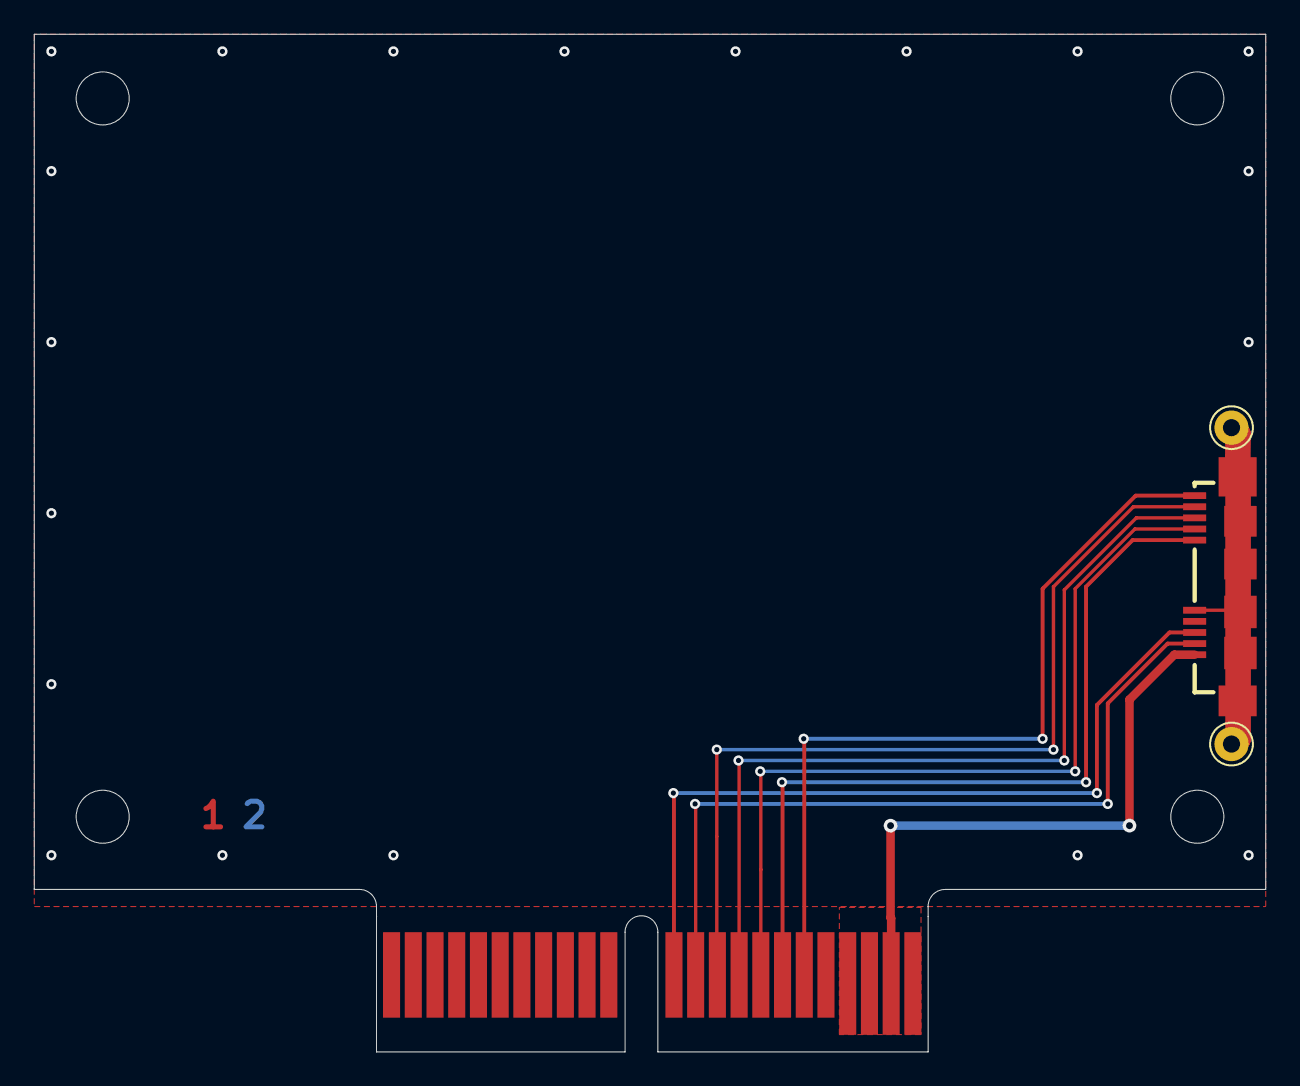
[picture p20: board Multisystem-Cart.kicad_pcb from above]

Board: 2 copper layers, 72.0 x 59.5 mm, 4 parts (1 on the bottom side), 11 nets.

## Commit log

2023-06-20 Add files via upload
    Production release of Multisystem Console motherboard for MiSTer - (23005-3) Issue 3 - 2023
    Full open-source release for the community.
    [23005.PrjPCB, 23005.xls, 23005_1.SchDoc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]
2024-12-06 KiCad template files for Multisystem1/2 Cartridges
    Added Multisystem & Multisystem 2 KiCad Cartridge PCB and Schematic templates for designing your own cartridge PCB's for MultisystemFPGA
    [Multisystem-Cart.kicad_pcb, Multisystem-Cart.kicad_sch]
2025-07-15 Move cart templates to separate folder
    [Multisystem-Cart.kicad_pcb, Multisystem-Cart.kicad_sch]
2025-09-30 Clarify cartridge connector descriptions
